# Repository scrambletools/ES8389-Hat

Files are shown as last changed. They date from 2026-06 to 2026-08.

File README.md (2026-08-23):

# Scramble Hat-trik — ES8389 Audio Codec HAT

A compact 4-layer audio I/O HAT that stacks on a Waveshare **ESP32-P4** carrier and
gives it a studio-style balanced input and a headset/line output, bridged to the host
over **I²S** (audio) and **I²C** (control). Its headline trick: it taps the carrier's
**802.3 PoE** rail to generate switchable **~48 V-class phantom power** for condenser
microphones — no separate supply.

> **Target carrier:** a Waveshare ESP32-P4-ETH board with PoE module. You will need to solder taps on the output of the bridge rectifiers of the PoE module and connect those wires to J5 on the hat.

---

## Capabilities

- **Balanced analog input** — Neutrik **XLR / ¼″ (6.35 mm) combo** jack (J1) into the
  ES8389 ADC, with input coupling and ESD protection.
- **PoE-tapped phantom power** — ~48 V phantom (tracks the 46–57 V PoE rail) through the
  standard 6.81 kΩ feed pair, **manually switched** (SW1) and **opto-isolated**, with a
  **white presence LED**, a resettable polyfuse, and a TVS rail clamp.
- **Headset / line output** — 3.5 mm **TRRS** jack (J2): stereo output from the DAC plus
  an **electret mic-bias** input path.
- **Stereo audio codec** — Everest **ES8389** (QFN-24): I²S/PCM audio + I²C control.
- **Clean analog power** — ultra-low-noise LDO (TPS7A2033) and ferrite-isolated AVDD.
- **Isolation barrier** — the phantom / XLR side (PGND) is kept separate from the carrier
  audio ground (AGND), bridged only by a **2.2 nF Y2 safety cap** (C19), with a DNP 0 Ω
  ground-lift option (R14).
- **External display header** — 4-pin **I²C** breakout (J6: 3V3 / GND / SDA / SCL) for an
  off-board display.
- **Manufacturable** — JLCPCB gerbers, drills, BOM and placement files are checked in;
  most parts are machine-assembled.

## Signal & power flow

```
  XLR / 6.35" combo (J1) ──coupling──▶ ES8389 ADC ──▶ I²S ──▶ ESP32-P4 carrier
         ▲ phantom
  PoE (J5) ─F1─▶ SW1 ─opto OK1─▶ P-FET Q1 ─▶ 6.81k feed ─▶ XLR pins 2 & 3

  ESP32-P4 carrier ──▶ I²S ──▶ ES8389 DAC ──coupling──▶ TRRS out (J2)
  ESP32-P4 carrier ◀──▶ I²C ◀──▶ ES8389        (+ external display header J6)
```

## Connectors & controls

| Ref | Part | Function |
|---|---|---|
| **J1** | Neutrik NCJ6FA-H | XLR / ¼″ combo — balanced mic/line **input**; ¼″ side is a Hi-Z **instrument input** with auto-detect *(hand-solder)* |
| **J2** | CUI SJ-3524 TRRS | 3.5 mm headset — stereo **output** + electret mic *(hand-solder)* |
| **J3, J4** | 1×7 sockets (8.5 mm) | mezzanine to the carrier — I²S, I²C, power |
| **J5** | 1×2 header | **PoE** rail input from the carrier's PoE module *(hand-solder)* |
| **J6** | 1×4 header | external **I²C** display (3V3 / GND / SDA / SCL) — *DNP; hand-fit (top side) only for a display harness. Eurorack builds don't need it: the interposer drives the display directly* |
| **SW1** | SPDT slide | **phantom power** on/off (manual) — *DNP; populate only in builds that use phantom.* Unpopulated = phantom permanently off; for switchless always-on phantom, bridge SW1 pads 1–2 instead |

## Key components

| Ref | Part | Role |
|---|---|---|
| **U1** | Everest ES8389 (QFN-24) | stereo audio codec |
| **U2** | TI TPS7A2033 | ultra-low-noise 3.3 V analog LDO |
| **OK1** | Everlight EL3H7 (80 V) | opto-isolated phantom enable |
| **Q1** | Vishay Si2325DS | P-FET phantom high-side switch |
| **F1** | 100 mA / 60 V PPTC | phantom / PoE overcurrent protection |
| **D6** | SMBJ58CA TVS | PoE-rail clamp |
| **D8** | white LED | phantom-present indicator |
| **C19** | 2.2 nF Y2 | isolation-barrier safety cap |

## Board

- **≈ 51.4 × 21.1 mm**, **4-layer** (F.Cu / In1.Cu / In2.Cu / B.Cu), 1.6 mm.
- Components on **both sides** (SMD top + bottom) plus a few through-hole connectors.
- Mechanical CAD (enclosure, mounting brackets, faceplates) is maintained outside this repo.

## Host integration

The codec carries audio over **I²S** and is controlled over **I²C**. Its I²C address is
set by the AD0/AD1 straps (R3/R4); R1/R2 are the SDA/SCL pull-ups. Typical firmware is
**ESPHome** or **ESP-ADF** configured for an external I²S codec.

## Mezzanine pinout (J3 / J4)

The header assignment is chosen so **one unmodified board works on two
hosts**: the Waveshare ESP32-P4-ETH carrier it was designed for, and a
**Raspberry Pi Pico** — the hat's footprint (2.54 mm pitch, ~17.8 mm row
spacing, 51 × 21 mm outline) lands exactly on the Pico's USB-end pins
1–7 / 40–34.

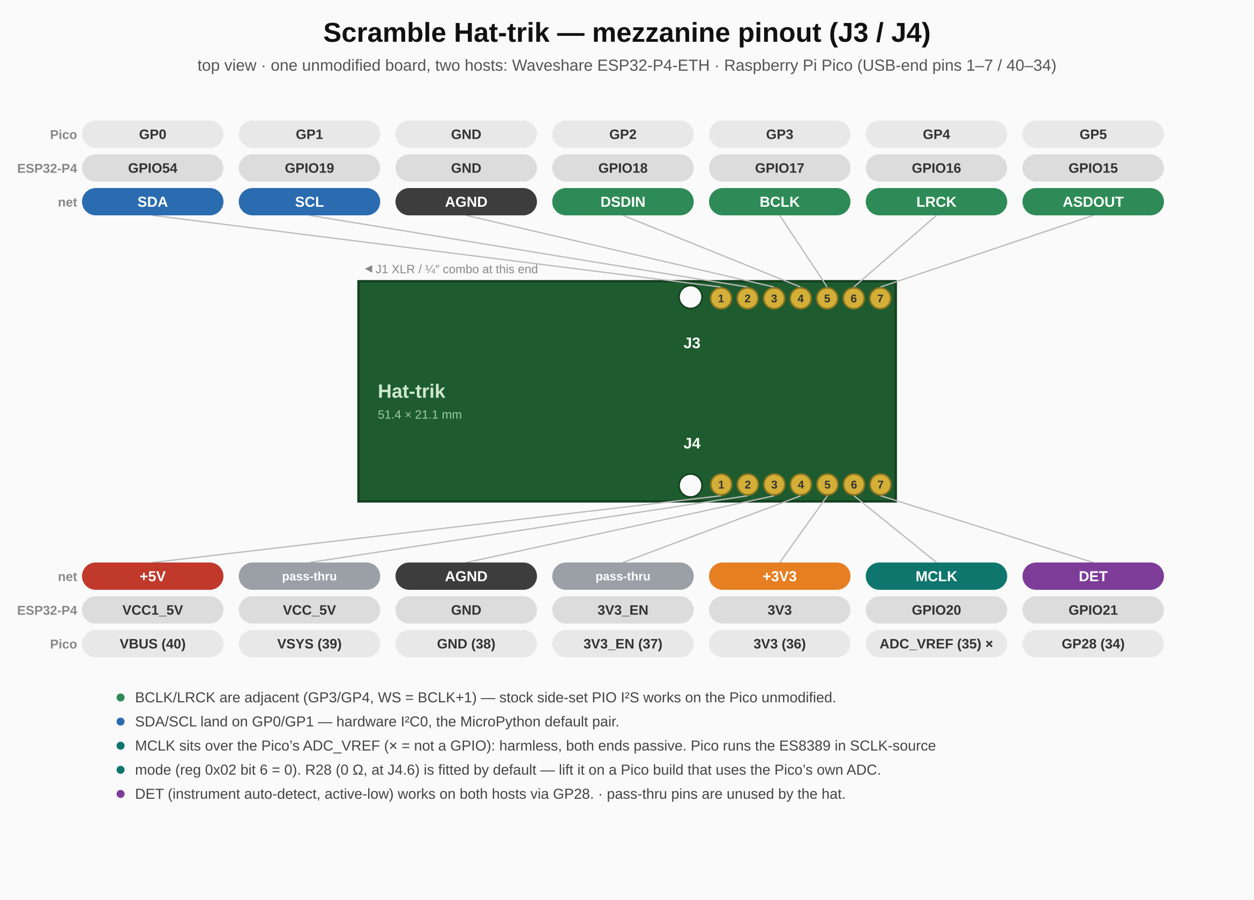
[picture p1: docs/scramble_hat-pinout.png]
Mezzanine pinout


| J3 pad | net | P4-ETH | Pico | | J4 pad | net | P4-ETH | Pico |
|---|---|---|---|---|---|---|---|---|
| 1 | `SDA` | GPIO54 | GP0 | | 1 | `+5V` | VCC1_5V | VBUS |
| 2 | `SCL` | GPIO19 | GP1 | | 2 | *pass* | VCC_5V | VSYS |
| 3 | `AGND` | GND | GND | | 3 | `AGND` | GND | GND |
| 4 | `DSDIN` | GPIO18 | GP2 | | 4 | *pass* | 3V3_EN | 3V3_EN |
| 5 | `BCLK` | GPIO17 | GP3 | | 5 | `+3V3` | 3V3 | 3V3(OUT) |
| 6 | `LRCK` | GPIO16 | GP4 | | 6 | `MCLK` | GPIO20 | ADC_VREF — unused |
| 7 | `ASDOUT` | GPIO15 | GP5 | | 7 | `DET` | GPIO21 | GP28 |

Why it lands this way:

- **BCLK/LRCK adjacent** (GP3/GP4, WS = BCLK + 1) — stock side-set PIO
  I²S implementations work unmodified on the Pico.
- **SDA/SCL on GP0/GP1** — a hardware I²C0 pair and MicroPython's default.
- **MCLK sits over the Pico's ADC_VREF**, which is harmless: both ends are
  passive (ADC_VREF is a filtered rail, the codec's MCLK is a hi-Z input),
  so a full 40-pin header can be fitted. The Pico runs the ES8389 in
  **SCLK-source mode** (reg 0x02 bit 6 = 0 — the codec clocks itself from
  BCLK; supported combos cover 44.1 k/48 k at 16/32-bit). The P4 keeps a
  true MCLK on GPIO20. Never jumper a Pico GPIO into a fitted J4.6.
  **R28** (0 Ω 0805, fitted by default) sits in series right at J4.6:
  lift it on a Pico build that uses the Pico's own ADC, so the hat's MCLK
  trace can't couple noise into ADC_VREF — or use its codec-side pad as
  the MCLK injection point for an advanced Pico build (192 kHz needs a
  real MCLK).
- **DET on GP28** — instrument auto-detect readback works on both hosts.

Pico caveats: `+5V` is VBUS, so the analog LDO only runs on USB power;
**phantom power is unavailable** (no PoE front end — see the phantom
section below); full-duplex I²S needs a custom PIO RX machine against
the TX clocks; no ES8389 driver exists for the Pico yet (port from
ESP-ADF or the mainline Linux `es8389.c`). For low BCLK jitter set
`sys_clk` to 153.6 MHz so 3.072 MHz divides exactly.

## Power & host-connection notes

- **USB-C and PoE at the same time is safe.** The carrier has an onboard
  power mux (PoE-priority P-FET + Schottky), so the supplies never fight
  and the PC's USB port can't be back-driven; the 48 V PoE line side stays
  behind the PoE module's transformer isolation (Y-cap bridge only), with
  or without phantom switched on. Flashing/serial over USB while running
  on PoE is the intended debug workflow.
- **Don't hot-plug USB mid-recording** — the ground-equalization transient
  can print as a pop at +36 dB mic gain. Connect first, then record.
- **Bench use on USB only:** leave phantom off (SW1 open/unpopulated) —
  with phantom on, K1/K2 close and reconnect the unpowered PoE module,
  which injects mains hum into the input.
- **Eurorack builds:** USB-C for flashing/serial works while Synthia
  powers the carrier from the rack — the interposer feeds the carrier's
  pre-mux node (bench-verified), so the same USB power mux applies. Avoid
  leaving USB plugged in with the rack powered off (it back-feeds the
  module's buck output); details in the Synthia repo.

## Phantom power source (the PoE tap)

Phantom power is the one hat feature that needs more than the mezzanine:
the 48 V-class rail is **tapped from the PoE bus** and enters the hat on
**J5** (pin 1 = `TAP_HV` +, pin 2 = `TAP_GND` −). On the ESP32-P4-ETH
carrier, the RJ45 mag-jack's pair centre taps run raw to the H7 header;
the **plug-in PoE module** on H7 carries the bridge rectifiers (BD1/BD2)
that turn them into 37–57 V DC before its isolated DC-DC makes the 5 V.
**Tap the two bridge-rectifier outputs on the PoE module** — `+` to
J5.1, `−` to J5.2. The module has **no connector for the tap**, so the
two leads are hand-soldered directly to the rectifier output pins; keep
them reasonably short:

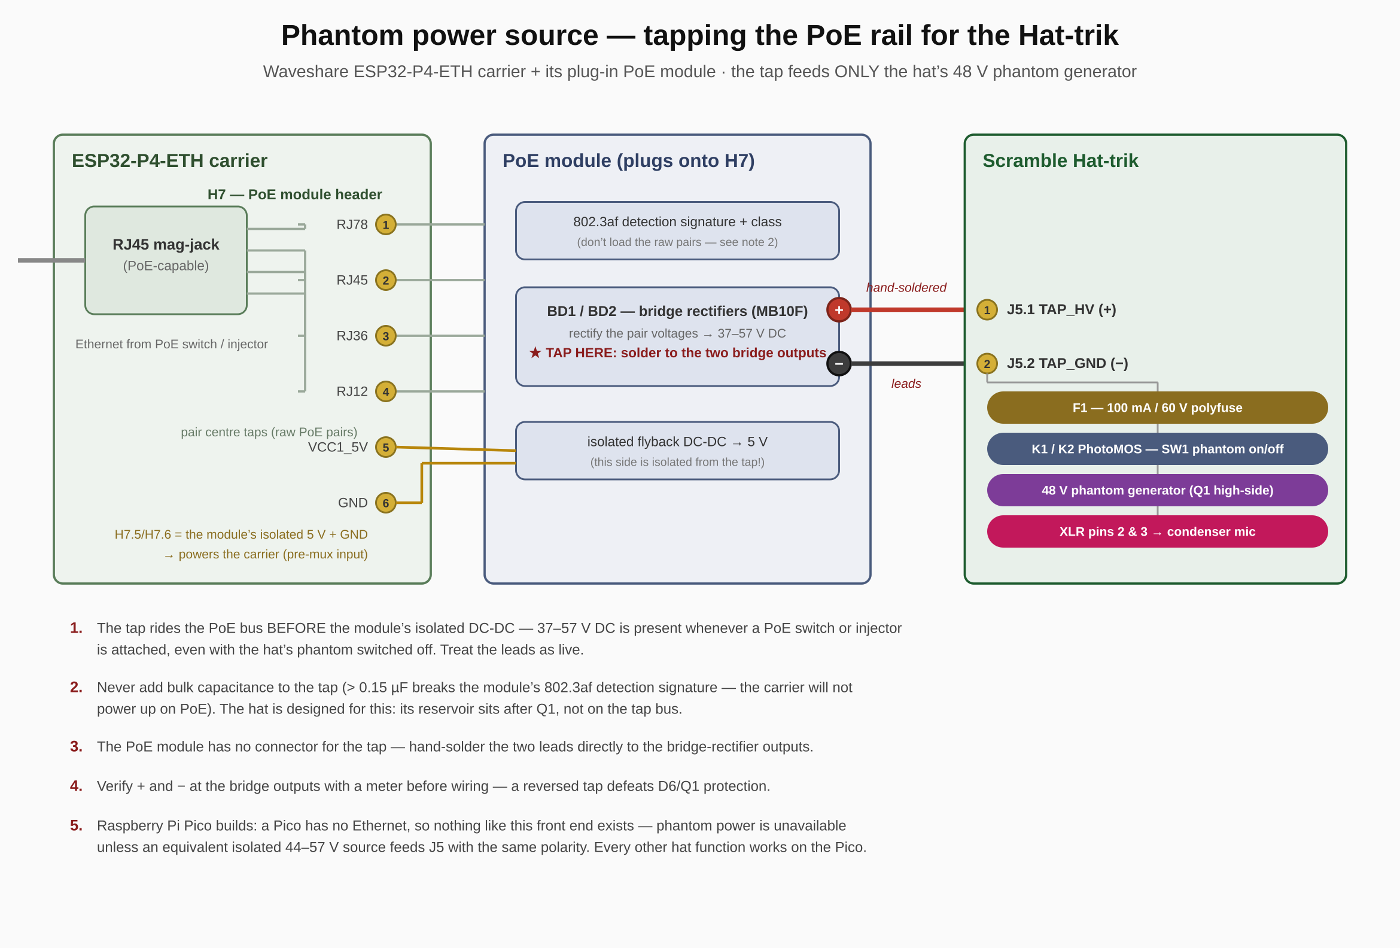
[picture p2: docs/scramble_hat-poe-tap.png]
PoE tap for phantom power


- The tap sits **before** the module's isolation barrier: 37–57 V is
  present whenever a PoE switch/injector is attached, even with SW1 off.
- **Never add bulk capacitance to the tap** (> 0.15 µF breaks the
  module's 802.3af detection signature and the carrier won't power up).
  The hat is designed for this — its reservoir sits after Q1.
- Verify `+`/`−` with a meter at the bridge outputs before wiring; a
  reversed tap defeats the D6/Q1 protection.
- **Raspberry Pi Pico builds: phantom power is unavailable.** A Pico has
  no Ethernet, so nothing like this PoE front end exists — the XLR
  condenser path is dead unless you feed J5 from an equivalent
  **isolated** 44–57 V source with the same polarity. Every other hat
  function (instrument input, dynamic mics, headphone/line out, display)
  works normally on a Pico.

## Microphone setups

Two validated configurations, using the AVB endpoint firmware's controls
(ES8389 PGA via the entity's Mic Gain control; digital gain via the talker's
`ESP_AVB_TALKER_MIC_DIGITAL_GAIN_DB` Kconfig, which also engages an always-on
DC-block ahead of the gain):

| | Condenser (phantom) | Dynamic |
|---|---|---|
| Phantom switch (SW1) | ON | OFF |
| PoE feed (J5) | connected + powered | **disconnect the PoE module** (see note) |
| ES8389 PGA gain | +36 dB | +36 dB (ceiling is +36.5 dB) |
| Digital gain (Kconfig) | 0 dB | **+20 dB** |

Notes:

- **Unpowered PoE module injects mains hum.** With the PoE module installed but
  not powered, the input picks up ~60 Hz mains at near full scale even with SW1
  off — remove/disconnect the module (J5 feed) when running without PoE.
  *(Addressed in the current design: SW1 off now opens both PoE-tap lines
  through the K1/K2 PhotoMOS relays, so the module can stay connected.)*
- Dynamic microphones sit ~20–30 dB below condenser output; the ES8389 PGA
  ceiling (+36.5 dB) alone leaves them ~-40 dBFS, hence the digital gain stage.
- Mic Gain writes above the PGA ceiling **clamp silently** — verify the value
  the response reports, not the value requested.
- The input is wired differential (MIC1P/1N) at the codec; both mic types run
  balanced through the XLR.

## Instrument (guitar) input

The ¼″ side of J1 feeds a high-impedance buffer (U3, ~500 kΩ input) into the
codec's MIC1 channel through an analog mux (U4). Inserting a **mono TS plug**
(guitar cable) shorts the jack's Ring contact to the Sleeve, pulling the
`DET` line low — this automatically switches MIC1 from the XLR mic path to
the buffered instrument path, and is readable by the carrier on **J4.7**
(input, active-low = instrument present). Remove the plug (or use an XLR
mic) and the input returns to the mic path. Phantom power never reaches the
¼″ contacts.

**Hardwiring a guitar without installing the Neutrik connector** — three
connections on the J1 footprint, not two:

| Guitar wire | Pad | Note |
|---|---|---|
| Tip (signal) | either **T** pad | the two T holes are the same net (`GTIP`); one is enough |
| Sleeve (ground) | **S** pad | `PGND`; the larger **G** pad is the same net if a thicker wire is used |
| — | jumper **R → S** | **required.** With no jack fitted, nothing shorts Ring to Sleeve, so `DET` stays high and the mux stays on the (absent) XLR path — the guitar would be silent. The jumper forces instrument mode. Easiest form: populate **R27** (0805 0 Ω, DNP by default) — it shorts `DET` to `PGND` on-board. Remove/leave it off if the Neutrik is fitted. |

**Eurorack module link (J7):** instead of hand-wiring, an optional 1×4
female socket **J7** (8.5 mm stacking, same series as J3/J4, DNP by
default) direct-mates the **Synthia** eurorack interposer's J8 header. Populate J7
**only when J1 is absent** (they use the same input path), and populate
**R27** with it (the module's input jack can't pull `DET` low). Pinout:
1 = `GTIP`, 2 = `PGND`, 3 = `AGND`, 4 = `HP_L_OUT` — signals on the outer
pins with both grounds between them.

**Eurorack + display:** the interposer drives a display directly from its
own display socket (J10, on the main GND/3V3/I²C nets), so **J6 can stay
DNP in eurorack builds** — no bottom-side fitting needed. Fit J6 (top
side) only for a normal display harness in non-rack builds.

**Cable:** use two-core shielded cable (the input is high impedance and
hums otherwise) — one core to **T** (signal), the other core to **S**
(return), and the **shield joined to S at the hat end only**; at the guitar
end connect just the two cores (tip / sleeve) and trim + insulate the
shield. The return current then flows in the tightly-coupled core pair
while the shield does pure screening — bonding it at both ends would let
ground-loop and pickup currents flow through it in series with the signal.
For very short runs (a few cm) plain coax — center to T, shield as the
return to S, connected at both ends — also works.

## Mono amplifier output (hardwiring J2)

To feed a mono amplifier that expects only tip and sleeve, skip the 3.5 mm jack
and solder wires directly to the J2 footprint. **Careful:** J2 is wired as a
**CTIA TRRS** headset jack, so the pad named `S` is *not* ground — on CTIA the
physical sleeve is the microphone conductor.

| Amp wire | Pad | Note |
|---|---|---|
| Tip (signal) | **T** | `HP_L_OUT` — left audio channel |
| Sleeve (ground) | **TN** | `AGND` — audio ground. **Do not use the `S` pad**: it is the headset-mic line (`MIC2_RAW`) and carries mic bias — grounding it gives hum and injects into the MIC2 input. |

Notes:

- This taps the **left channel only**; have firmware output a mono downmix if
  the source is stereo. Do **not** bridge the `T` and `R` pads to "sum" the
  channels — that shorts the two DAC output stages into each other. (A passive
  sum, if ever wanted, is a ~1 kΩ resistor from each of T and R into the amp
  tip.)
- An amp input (typically ≥10 kΩ) is a much lighter load than headphones, so
  the 22 µF output coupling caps give essentially full bass extension here.
- Unlike the J1 guitar hardwire, **no jumper is required** — J2 has no
  plug-detect circuit.
- **Cable:** use two-core shielded cable — one core to **T** (signal), the
  other core to **TN** (return), **shield joined to TN at the hat end
  only**; at the amp end connect just the two cores (tip / sleeve) and
  trim + insulate the shield. This keeps the shield free of audio and
  ground-loop current (which its resistance would otherwise convert to hum
  in series with the signal) while still screening the run. This link is
  forgiving (low-Z source into a ≥10 kΩ amp input), so for runs under
  ~10 cm plain coax with the shield as the return, connected at both ends,
  is also fine.

## Repository layout

| Path | Contents |
|---|---|
| `scramble_hat.kicad_sch` / `.kicad_pcb` | hierarchical schematic + layout |
| `BOM.csv` | bill of materials — **single source of truth** |
| `fab/` | JLCPCB gerbers, drills, BOM, CPL — see [`fab/README.md`](fab/README.md) |
| `tools/gen_fab.py` | regenerate every production file from the design |
| `tools/check_sync.py` | verify schematic ↔ PCB netlist agreement |
| `lib/` | project symbols, footprints, 3D models |
| `docs/` | schematic + silkscreen PDFs |

## Manufacturing

See **[`fab/README.md`](fab/README.md)** for the full ordering guide. In short: JLCPCB
fabricates and assembles most parts; you **hand-solder J1, J2, J5 and C19** (the Y-cap),
and **R14 is left unpopulated** (DNP ground-lift jumper). **J6** (display header) is also
DNP — hand-fit it only when a display is used (top side normally, bottom side for the
eurorack stack). Regenerate all fab outputs with:

```sh
python3 tools/gen_fab.py
```

> ⚠️ Before committing an assembly order, verify part rotations in JLCPCB's preview —
> especially **U1** (the QFN's rotation is applied manually and is a best estimate).

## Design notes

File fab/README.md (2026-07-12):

# Scramble Hat-trik — Fabrication & Assembly Files

Production files for **JLCPCB** (PCB fab + PCBA assembly). Board is an ES8389
audio codec HAT for the Waveshare ESP32-P4-Nano carrier (XLR/¼" combo input,
PoE-tapped phantom power, TRRS output, I²S/I²C to the carrier).

- **Board size:** ~51.4 × 21.1 mm
- **Layers:** 4 (F.Cu / In1.Cu / In2.Cu / B.Cu)
- **Assembly:** 28 BOM line items (48 placements/board) machine-assembled;
  3 connectors + 1 Y-cap hand-soldered; 1 part unpopulated.

> Regenerate everything with **`python3 tools/gen_fab.py`** (see the bottom).
> These files are committed from the design in the repo root; don't hand-edit them.

---

## Files

| File | Purpose |
|---|---|
| `scramble_hat-gerbers.zip` | **PCB fab** — all gerbers + drills (upload this) |
| `scramble_hat-*.gbr`, `*.drl`, `*.gbrjob` | Loose copies of the layers/drills in the zip |
| `scramble_hat-BOM.csv` / `.xlsx` | **Assembly BOM** — JLCPCB upload format (Comment, Designator, Footprint, LCSC#) |
| `Sample-BOM_JLCSMT.xlsx`, `JLCSMT_Sample_CPL1.xlsx` | JLCPCB's blank format templates (reference only) |
| `scramble_hat-CPL.csv` | **Placement file** — generated by `tools/gen_fab.py` with JLCPCB rotation corrections + the U1 fix baked in (still verify — see below) |

---

## How to order

### 1. PCB fabrication
Upload **`scramble_hat-gerbers.zip`**. Set **4 layers**; the rest can be
JLCPCB defaults (1.6 mm, HASL/ENIG, no controlled impedance required).

### 2. PCB assembly (PCBA)
1. **Enable "PCBA"** and turn on **through-hole / THT component assembly** at
   checkout — several parts are through-hole (see the assembled-THT list below).
2. Upload the **BOM**: `scramble_hat-BOM.csv`.
3. Upload the **CPL / placement file** — **you must generate this** (see next section).

### 3. ⚠️ CPL / placement — verify rotations before ordering
`scramble_hat-CPL.csv` is generated by `tools/gen_fab.py`. Its rotations were
**cross-validated against the KiCad Fabrication Toolkit plugin** — they match on
every placed part — and it additionally corrects **U1** (`+270°`), which the
plugin's auto-database misses because of the custom `ES8389_QFN24_P0.35mm` name.

Even so, **verify every rotation in JLCPCB's assembly preview** before ordering —
especially **U1 (QFN)**, whose correction is a best estimate. The preview overlays
each part on its land; rotate anything that looks off.

Parts carrying a rotation correction (double-check these first): `U1`, `U2`, `Q1`,
`D1`, `D2`, `OK1`. The CPL already excludes the hand-solder (J1/J2/J5) and DNP
(R14) parts via their `exclude_from_pos_files` / `dnp` PCB flags.

---

## Who solders what

| Set | Parts | Notes |
|---|---|---|
| **JLCPCB — SMT** | everything not listed below | machine-placed |
| **JLCPCB — THT** (enable at checkout) | `J3`, `J4` (carrier sockets), `SW1` (slide switch), `J6` (I²C header) | wave/hand-soldered by JLCPCB |
| **You — hand-solder after arrival** | `J1` (XLR/¼" combo jack), `J2` (TRRS jack), `J5` (PoE header), `C19` (Y2 safety cap) | J2 is out of stock at LCSC (source separately); J5 is where you wire the PoE module; C19 is a user-sourced 7.5 mm Y2 disc (Murata DE2E3 / TDK CS11) — kept off the JLC line so its niche stock never blocks the order |
| **Unpopulated (DNP)** | `R14` | 0 Ω ground-lift jumper, deliberately left off |

---

## Sourcing notes
- **F1** polyfuse (`1812L010/60DR`, C207062) — stock is thin (~120); re-check at order time. It's the voltage-critical 60 V part — do not substitute a lower-voltage 1812.
- Extended-library parts (U1, EL3H7 opto, TVS, R16, the 6.81 k, J6, etc.) each carry JLCPCB's one-time extended-part fee.
- Per-board BOM parts ≈ **$8** at qty-10 pricing (dominated by the J1/J2 jacks); budget more for the one-time extended fees.

---

## Regenerating these files
From the repo root, with KiCad closed:

```sh
python3 tools/gen_fab.py
```

One script rebuilds the gerbers, drills, zip, **BOM** (from the root `BOM.csv` —
single source of truth — with DNP rows dropped) and the **CPL** (with JLCPCB
rotation corrections). Needs `kicad-cli` on PATH and `openpyxl` for the `.xlsx`
BOM. The rotation-correction table is at the top of the script — extend it when
you add parts, and always re-verify in JLCPCB's preview.

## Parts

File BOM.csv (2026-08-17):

Comment | Designator | Qty | MPN | Manufacturer | Footprint | LCSC Part # | JLCPCB Class | Mount | DNP | Unit Price USD | Notes | Datasheet
ES8389 audio codec | U1 | 1 | ES8389 | Everest Semi | QFN-24 3x3 P0.35mm | C22380673 | Extended | SMT |  | 0.712 | Custom 0.35mm-pitch footprint (scramble_hat lib) | https://datasheet.lcsc.com/datasheet/pdf/4ae5a2e8327541a33b0c2afa9b0074da.pdf?productCode=C22380673
Ultra-low-noise LDO 3.3V | U2 | 1 | TPS7A2033PDBVR | Texas Instruments | SOT-23-5 | C2862740 | Extended | SMT |  | 0.2102 | AVDD analog LDO; +5V -> +3V3_A | https://datasheet.lcsc.com/datasheet/pdf/e9493c53ea71c523359aed2b3e8071a4.pdf?productCode=C2862740
Optocoupler 80V | OK1 | 1 | EL3H7(C)(TA)-VG | Everlight | SOP-4-1.27mm | C17549577 | Extended | SMT |  | 0.0741 | PHANTOM_EN isolation; 80V Vceo; SOP-4 1.27mm half-pitch; pinout 1=A 2=K 3=E 4=C. Same die/package/CTR-bin as EL3H7(C)(TA)-G (C92243, went stock-0 2026-07-26); -VG = halogen-free packing. CTR 200-400%. | https://www.everlighteurope.com/custom/files/datasheets/DPC-0000031.pdf
P-MOSFET 150V | Q1 | 1 | Si2325DS-T1-GE3 | Vishay | SOT-23 | C60773 | Extended | SMT |  | 0.4946 | Phantom switch; gate clamped by D7 | https://datasheet.lcsc.com/datasheet/pdf/8db77570eae4643cba5e4135ab2c0e7e.pdf?productCode=C60773
ESD diode, 3.3V bidir | D1, D2 | 2 | PESD3V3L1BA-N | BORN | SOD-323 | C316020 | Extended | SMT |  | 0.0611 | Mic-line ESD (was 4-line PESD3V3L4UG/C70500 using 1 of 4 channels). Bidirectional 2-pin: no polarity/rotation. Saves ~$0.14/board | https://datasheet.lcsc.com/datasheet/pdf/a036bfae0471726dc4b012d9a313715c.pdf?productCode=C316020
TVS 58V 600W bidir | D6 | 1 | SMBJ58CA | Littelfuse | SMA | C151267 | Extended | SMT |  | 0.121 | PoE rail clamp | https://datasheet.lcsc.com/datasheet/pdf/4ab84a227fae39f9eac85241b8264ead.pdf?productCode=C151267
Zener 12V 0.5W | D7 | 1 | MMSZ5242BT1G | onsemi | SOD-123 | C82050 | Basic/Ext | SMT |  | 0.0354 | Q1 gate clamp | https://datasheet.lcsc.com/datasheet/pdf/03657490163bd8bf58522f8bf8ee19e0.pdf?productCode=C82050
LED, white | D8 | 1 | KT-0805W | Hubei KENTO | 0805 | C34499 | Basic | SMT |  | 0.0203 | Phantom-present indicator (white); KT-0805W Basic in-stock | https://datasheet.lcsc.com/datasheet/pdf/48953f05e6e6e0a517af2e319c9c297c.pdf?productCode=C34499
PPTC 100mA hold / 60V | F1 | 1 | 1812L010/60DR | Littelfuse | 1812 | C207062 | Extended | SMT |  | 0.2151 | True 1812 (matches board land); 100mA hold/300mA trip. prior 0ZCJ0005FF2E/C194141 is 1206 - wrong size | https://datasheet.lcsc.com/datasheet/pdf/f489f06aaead3504c46a5f46e8004a19.pdf?productCode=C207062
Ferrite 600R @100MHz | FB1 | 1 | BLM18AG601SN1D | Murata | 0603 | C19330 | Basic/Ext | SMT |  | 0.0149 | AVDD ferrite | https://datasheet.lcsc.com/datasheet/pdf/2d503a4b167da9bb5d0eb4a3fa711314.pdf?productCode=C19330
100nF 50V X7R | C1, C3, C4, C27, C28, C29 | 6 | CC0402KRX7R9BB104 | Yageo | 0402 | C131394 | Basic | SMT |  | 0.0157 |  | https://datasheet.lcsc.com/datasheet/pdf/23ccee80ee542e7cf156a772bb589942.pdf?productCode=C131394
1uF 25V X5R | C2, C5, C7, C8, C9, C12, C13, C20, C21, C23, C24, C25, C26 | 13 | CL05A105KA5NQNC | Samsung | 0402 | C52923 | Basic | SMT |  | 0.0266 |  | https://datasheet.lcsc.com/datasheet/pdf/02336ea48ea44ca18c72517dd3cb7b47.pdf?productCode=C52923
10uF 16V X5R | C6 | 1 | GRM21BR61C106KE15L | Murata | 0805 | C77075 | Basic | SMT |  | 0.0716 | AVDD bulk | https://datasheet.lcsc.com/datasheet/pdf/a4d1e2744bd5d44ba57842651a3fd598.pdf?productCode=C77075
1uF 100V X7R | C10, C11 | 2 | CC0805KKX7R0BB105 | Yageo | 0805 | C5370002 | Extended | SMT |  | 0.1307 | XLR coupling (phantom side); 100V for margin | https://datasheet.lcsc.com/datasheet/pdf/23ccee80ee542e7cf156a772bb589942.pdf?productCode=C5370002
22uF 10V X5R | C14, C15 | 2 | CL21A226MPQNNNE | Samsung | 0805 | C29277 | Extended | SMT |  | 0.1722 | HP coupling | https://datasheet.lcsc.com/datasheet/pdf/02336ea48ea44ca18c72517dd3cb7b47.pdf?productCode=C29277
100nF 100V X7R | C17, C30 | 2 | 0805B104K101NT | Fenghua | 0805 | C89258 | Extended | SMT |  | 0.026 | C17 = tap-line bridge; C30 = V_PHANTOM bypass at Q1 drain (PoE-converter hash filter; keep OFF the tapped bus - 802.3 detection limit). 100V rating required (57V rail). | https://datasheet.lcsc.com/datasheet/pdf/9f6ef17093b8d551f8b17af0626ff758.pdf?productCode=C89258
1uF 100V X7R | C18 | 1 | CL31B105KCHNNNE | Samsung | 1206 | C13832 | Extended | SMT |  | 0.1396 | Q1 gate soft-start | https://datasheet.lcsc.com/datasheet/pdf/02336ea48ea44ca18c72517dd3cb7b47.pdf?productCode=C13832
2.2nF Y2 300VAC | C19 | 1 | DE2E3SA222MA3BT02F | Murata | Disc TH 7.5mm | C524537 | n/a | TH | DNP | 0.087 | Hand-solder by user (Y2 safety cap; NOT JLC-assembled). X1/Y2 300/250VAC 2.2nF 7.5mm disc; source DigiKey/Mouser (Murata DE2E3) or TDK CS11-E2GA222MYNSA equivalent LCSC ALT (in stock 42k, $0.03): Hongzhi Y26F1E222M / C332371, Y2 250VAC 2.2nF P7.5 - same land. | https://datasheet.lcsc.com/datasheet/pdf/d99197b87f9afabff400cdbfcd3b51ea.pdf?productCode=C524537
2.2uF 10V X5R | C22 | 1 | CL05A225KP5NSNC | Samsung | 0402 | C107369 | Basic | SMT |  | 0.0239 | LDO output cap | https://datasheet.lcsc.com/datasheet/pdf/02336ea48ea44ca18c72517dd3cb7b47.pdf?productCode=C107369
10k 1% | R1, R2, R3, R4, R25 | 5 | RC0402FR-0710KL | Yageo | 0402 | C60490 | Extended | SMT |  | 0.0059 | I2C pullups + AD0/AD1 straps. C# was C25744 = UNI-ROYAL 0402WGF1002TCE (Basic) but now OUT OF STOCK; switched to the matching Yageo MPN C60490 (in stock ~92k). Verify Basic/Extended badge in JLC UI | https://datasheet.lcsc.com/datasheet/pdf/b426be3ce22c6de3e0c3a2248e49159e.pdf?productCode=C60490
6.81k 1% | R5, R6 | 2 | ERJ6ENF6811V | Panasonic | 0805 | C3025619 | Extended | SMT |  | 0.0082 | Phantom feed pair (no JLCPCB Basic for 6.81k 0805) | https://datasheet.lcsc.com/datasheet/pdf/ac61a13441f28ab6046e65784bfab8d2.pdf?productCode=C3025619
2.2k 1% | R7, R20 | 2 | AC0402FR-072K2L | Yageo | 0402 | C144773 | Basic | SMT |  | 0.0057 | Mic bias; C# C25879 stock-0 at LCSC 2026-07-26; swapped to C144773. | https://datasheet.lcsc.com/datasheet/pdf/3511efb0564cb1711d9237ab09d6e97b.pdf?productCode=C144773
33R 1% | R9, R10, R24 | 3 | RC0402FR-0733RL | Yageo | 0402 | C138002 | Basic | SMT |  | 0.0056 | HP output series; C# C25105 stock-0 at LCSC 2026-07-26; swapped to C138002. | https://datasheet.lcsc.com/datasheet/pdf/b426be3ce22c6de3e0c3a2248e49159e.pdf?productCode=C138002
100k 1% | R11, R13, R19, R22, R23 | 5 | RC0402FR-07100KL | Yageo | 0402 | C60491 | Basic | SMT |  | 0.0061 | Q1 gate pullup / opto pulldown; C# C25741 stock-0 at LCSC 2026-07-26; swapped to C60491. | https://datasheet.lcsc.com/datasheet/pdf/b426be3ce22c6de3e0c3a2248e49159e.pdf?productCode=C60491
1k 1% | R12 | 1 | RC0402FR-071KL | Yageo | 0402 | C106235 | Basic | SMT |  | 0.0062 | Opto LED current limit (switch -> opto); C# C11702 stock-0 at LCSC 2026-07-26; swapped to C106235. | https://datasheet.lcsc.com/datasheet/pdf/b426be3ce22c6de3e0c3a2248e49159e.pdf?productCode=C106235
0R | R14 | 1 | RC0402JR-070RL | Yageo | 0402 |  | n/a | DNP | DNP | 0.02 | Ground-lift jumper - not populated (true DNP)
15k 1% 1/4W | R16 | 1 | AC0805FR-7W15KL | Yageo | 0805 | C20142753 | Extended | SMT |  | 0.0085 | D8 LED current-limit (bright ~3mA); 1/4W anti-surge ~193mW at 57V rail | https://datasheet.lcsc.com/datasheet/pdf/3511efb0564cb1711d9237ab09d6e97b.pdf?productCode=C20142753
XLR / 6.35mm combo jack | J1 | 1 | NCJ6FA-H | Neutrik | TH combo | C368458 | n/a | TH | DNP | 2.6072 | Hand-solder (TH). Switched combo (A type), ~$1.82 vs FI $4.34; jack switch contacts unused | https://datasheet.lcsc.com/datasheet/pdf/9e398f1fdd271e3584b460a9821f2988.pdf?productCode=C368458
3.5mm TRRS jack | J2 | 1 | SJ-3524-SMT-TR | CUI | SMT |  | n/a | SMT | DNP | 1.40 | SJ-3524 family OUT OF STOCK at LCSC+JLCPCB (2026-06) - hand-solder from DigiKey 281298 (base -TR, 67k stock; any color variant fits) | https://www.sameskydevices.com/product/interconnect/connectors/audio-connectors/jacks/sj-3524-smt-tr
1x7 female socket, 8.5mm | J3, J4 | 2 | PM254V-11-07-H85 | XFCN | PinSocket_1x07_2.54mm TH | C2832270 | THT | TH |  | 0.0976 | JLCPCB THT-assembled (enable THT components at checkout); 8.5mm stack height | https://datasheet.lcsc.com/datasheet/pdf/5aa023c30ffb4f607882b69ea05af7aa.pdf?productCode=C2832270
1x2 pin header | J5 | 1 | PRPC002SAAN-RC | Sullins | PinHeader_1x02_2.54mm TH |  | n/a | TH | DNP | 0.30 | PoE module connection - hand-solder
1x4 pin header | J6 | 1 | B-2100S04P-A110 | Ckmtw | PinHeader_1x04_2.54mm TH | C124378 | Extended | TH | DNP | 0.055 | Hand-fit per build: top side for a display harness, BOTTOM side for the eurorack stack (mates interposer J9). Pinout 1=AGND 2=+3V3 3=SCL 4=SDA | https://datasheet.lcsc.com/datasheet/pdf/219f7e7eb5f34457895b2c164313179f.pdf?productCode=C124378
1x4 female socket, 8.5mm | J7 | 1 | PM254V-11-04-H85 | XFCN | PinSocket_1x04_2.54mm TH | C541851 | Extended | TH | DNP | 0.0703 | OPTIONAL: populate only when J1 is absent; direct-mates eurorack module J8 (same H85 stack series as J3/J4). Pin 1=GTIP 2=PGND 3=AGND 4=HP_L_OUT | https://datasheet.lcsc.com/datasheet/pdf/7912db05a9479e06d287e74aeb027dc2.pdf?productCode=C541851
0R jumper 0805 | R27 | 1 | 0805W8F0000T5E | UNI-ROYAL | 0805 | C17477 | Basic | SMT | DNP | 0.0101 | OPTIONAL: populate to force instrument mode (DET->PGND, replaces J1 ring-short); required when input arrives via J7 | https://datasheet.lcsc.com/datasheet/pdf/0a975aaa49b7c97f38a963127be4a823.pdf?productCode=C17477
0R jumper 0805 | R28 | 1 | 0805W8F0000T5E | UNI-ROYAL | 0805 | C17477 | Basic | SMT |  | 0.0101 | MCLK series link (J4.6 -> codec), fitted by default; lift only on a Pico build that uses the Pico's own ADC (isolates the MCLK trace from ADC_VREF) | https://datasheet.lcsc.com/datasheet/pdf/0a975aaa49b7c97f38a963127be4a823.pdf?productCode=C17477
SPDT slide switch (phantom on/off) | SW1 | 1 | SS-12D00-G3 | SOFNG | SW_Slide_SS-12D00-G3 TH | C22355741 | THT | TH | DNP | 0.0472 | OPTIONAL (DNP by default): populate for manual phantom on/off. Unpopulated = phantom permanently OFF (PHANTOM_SW floats, no LED drive). For always-on phantom without the switch, bridge pads 1-2 (+3V3 to PHANTOM_SW). | https://datasheet.lcsc.com/datasheet/pdf/7357551f1ab94cd5763cc9d7033faef8.pdf?productCode=C22355741
PhotoMOS SSR 400V (tap disconnect) | K1, K2 | 2 | KAQY214S | Cosmo | SOP-4 3.8x4.1mm | C2890344 | Extended | SMT |  | 0.6812 | 1-form-A AC/bidirectional MOSFET-output SSR; K1 breaks V_PoE tap, K2 breaks PGND tap, when phantom off (kills dynamic-mic buzz). Input LED off PHANTOM_SW via R17/R18. VERIFY pinout 1=A/2=K/3,4=load per C2890344; verify JLCPCB SMT-assembly vs hand-solder. | https://datasheet.lcsc.com/datasheet/pdf/c42aed2cb222c7a8c08f3ade74b70e5b.pdf?productCode=C2890344
470R 1% (PhotoMOS LED limit) | R17, R18 | 2 | RC0402FR-07470RL | Yageo | 0402 | C114877 | Basic | SMT |  | 0.0052 | K1/K2 input-LED current limit (~4.5mA at 3V3; KAQY214S Vf 1.2V, IFON<=3mA). Yageo RC0402FR family match; 306k stock; JLCPCB Economic-eligible. | https://datasheet.lcsc.com/datasheet/pdf/b426be3ce22c6de3e0c3a2248e49159e.pdf?productCode=C114877
Op-amp Hi-Z buffer (RRIO CMOS) | U3 | 1 | TLV9061IDBVR | Texas Instruments | SOT-23-5 | C398358 | Extended | SMT |  | 0.0967 | Guitar 1/4in Hi-Z buffer (~1M in), unity follower on +5V; drives mux U4. Pinout 1=OUT 2=V- 3=IN+ 4=IN- 5=V+ | https://datasheet.lcsc.com/datasheet/pdf/b3f500e21835dc38634fe987feaa838a.pdf?productCode=C398358
Analog switch triple SPDT | U4 | 1 | 74HC4053PW | Nexperia | TSSOP-16 | C5648 | Extended | SMT |  | 0.2602 | Mic/instrument mux: MIC1P/MIC1N source = XLR mic (no plug) or buffered guitar + PGND ref (plug). Select=DET (jack ring; also routed to J3.7 for firmware readback). +3V3 supply so DET/select are 3.3V-native and GPIO-safe; analog range 0-3.3V covers codec-bias signals. 2 of 3 sections used (Z spare). VERIFY TSSOP-16 rotation in JLCPCB preview | https://datasheet.lcsc.com/datasheet/pdf/176a996d087210c9e4d002f82a5fe329.pdf?productCode=C5648
1M 1% | R21, R26 | 2 | RC0402FR-071ML | Yageo | 0402 | C138033 | Basic | SMT |  | 0.0055 | Guitar buffer input bias -> ~1M input impedance; C# C26083 stock-0 at LCSC 2026-07-26; swapped to C138033. | https://datasheet.lcsc.com/datasheet/pdf/b426be3ce22c6de3e0c3a2248e49159e.pdf?productCode=C138033
ESD diode bidir 5.5V | D9 | 1 | TPD1E10B06DPYR | Texas Instruments | X1-SON-2 0.6x1.0mm | C48260 | Extended | SMT |  | 0.0414 | Guitar tip ESD clamp (GTIP-PGND); bidirectional +/-5.5V, 12pF. Tiny DFN - JLC-assembled; hand-rework alt: PESD5V0S1BB/C97640 SOD-523 | https://datasheet.lcsc.com/datasheet/pdf/338eb197fbc247888eaf2230887550ac.pdf?productCode=C48260

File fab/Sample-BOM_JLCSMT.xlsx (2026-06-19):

Comment | Designator | Footprint | JLCPCB Part #（optional）
100uF | C1 | CAP-SMD_L3.5-W2.8 | C16133
15K | R5,R6 | R0603 | C22809
DC-005-20A_C136744 | DC1 | DC-IN-TH_DC-005-20A | C136744
Header-Female-2.54_1x8 | P2,P3 | HDR-TH_8P-P2.54-V | C27438
K2-1102DP-C4SW-04 | SW1 | KEY-TH_4P-L6.0-W6.0-P4.50-LS6.5 | C110153
ATMEGA328P-PU | U1 | DIP-28_L34.6-W7.3-P2.54-LS10.2-BL | C33901
670688000 | USB1 | USB-B-TH_67068-8000 | C114097

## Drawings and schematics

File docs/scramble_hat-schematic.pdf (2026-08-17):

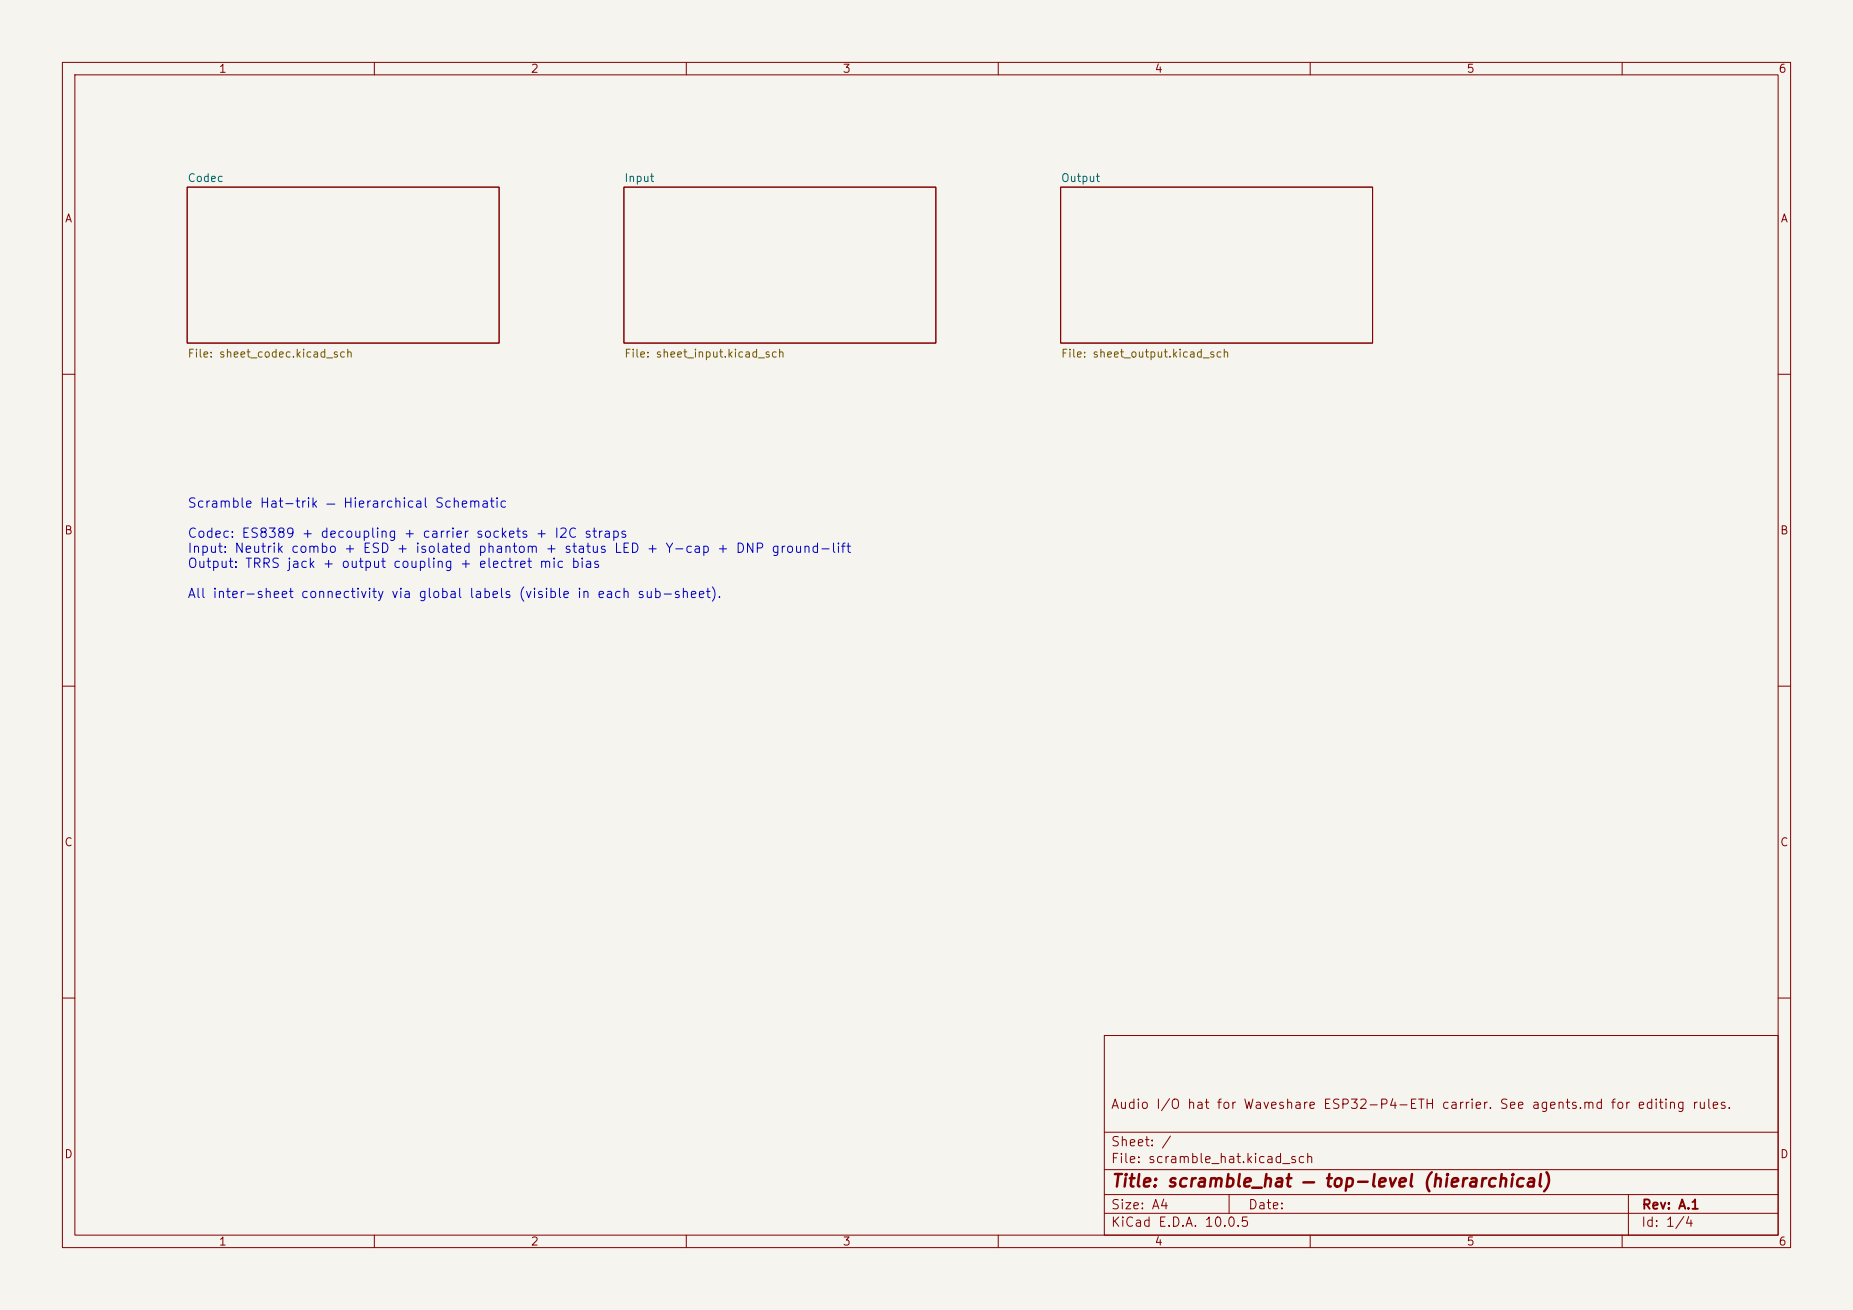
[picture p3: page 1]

Scramble Hat-trik — Hierarchical Schematic

Codec: ES8389 + decoupling + carrier sockets + I2C straps
Input: Neutrik combo + ESD + isolated phantom + status LED + Y-cap + DNP ground-lift
Output: TRRS jack + output coupling + electret mic bias

All inter-sheet connectivity via global labels (visible in each sub-sheet).

Audio I/O hat for Waveshare ESP32-P4-ETH carrier. See agents.md for editing rules.

Sheet: /
File: scramble_hat.kicad_sch
Title: scramble_hat — top-level (hierarchical)

Size: A4 | Rev: A.1
KiCad E.D.A. 10.0.5 | Id: 1/4

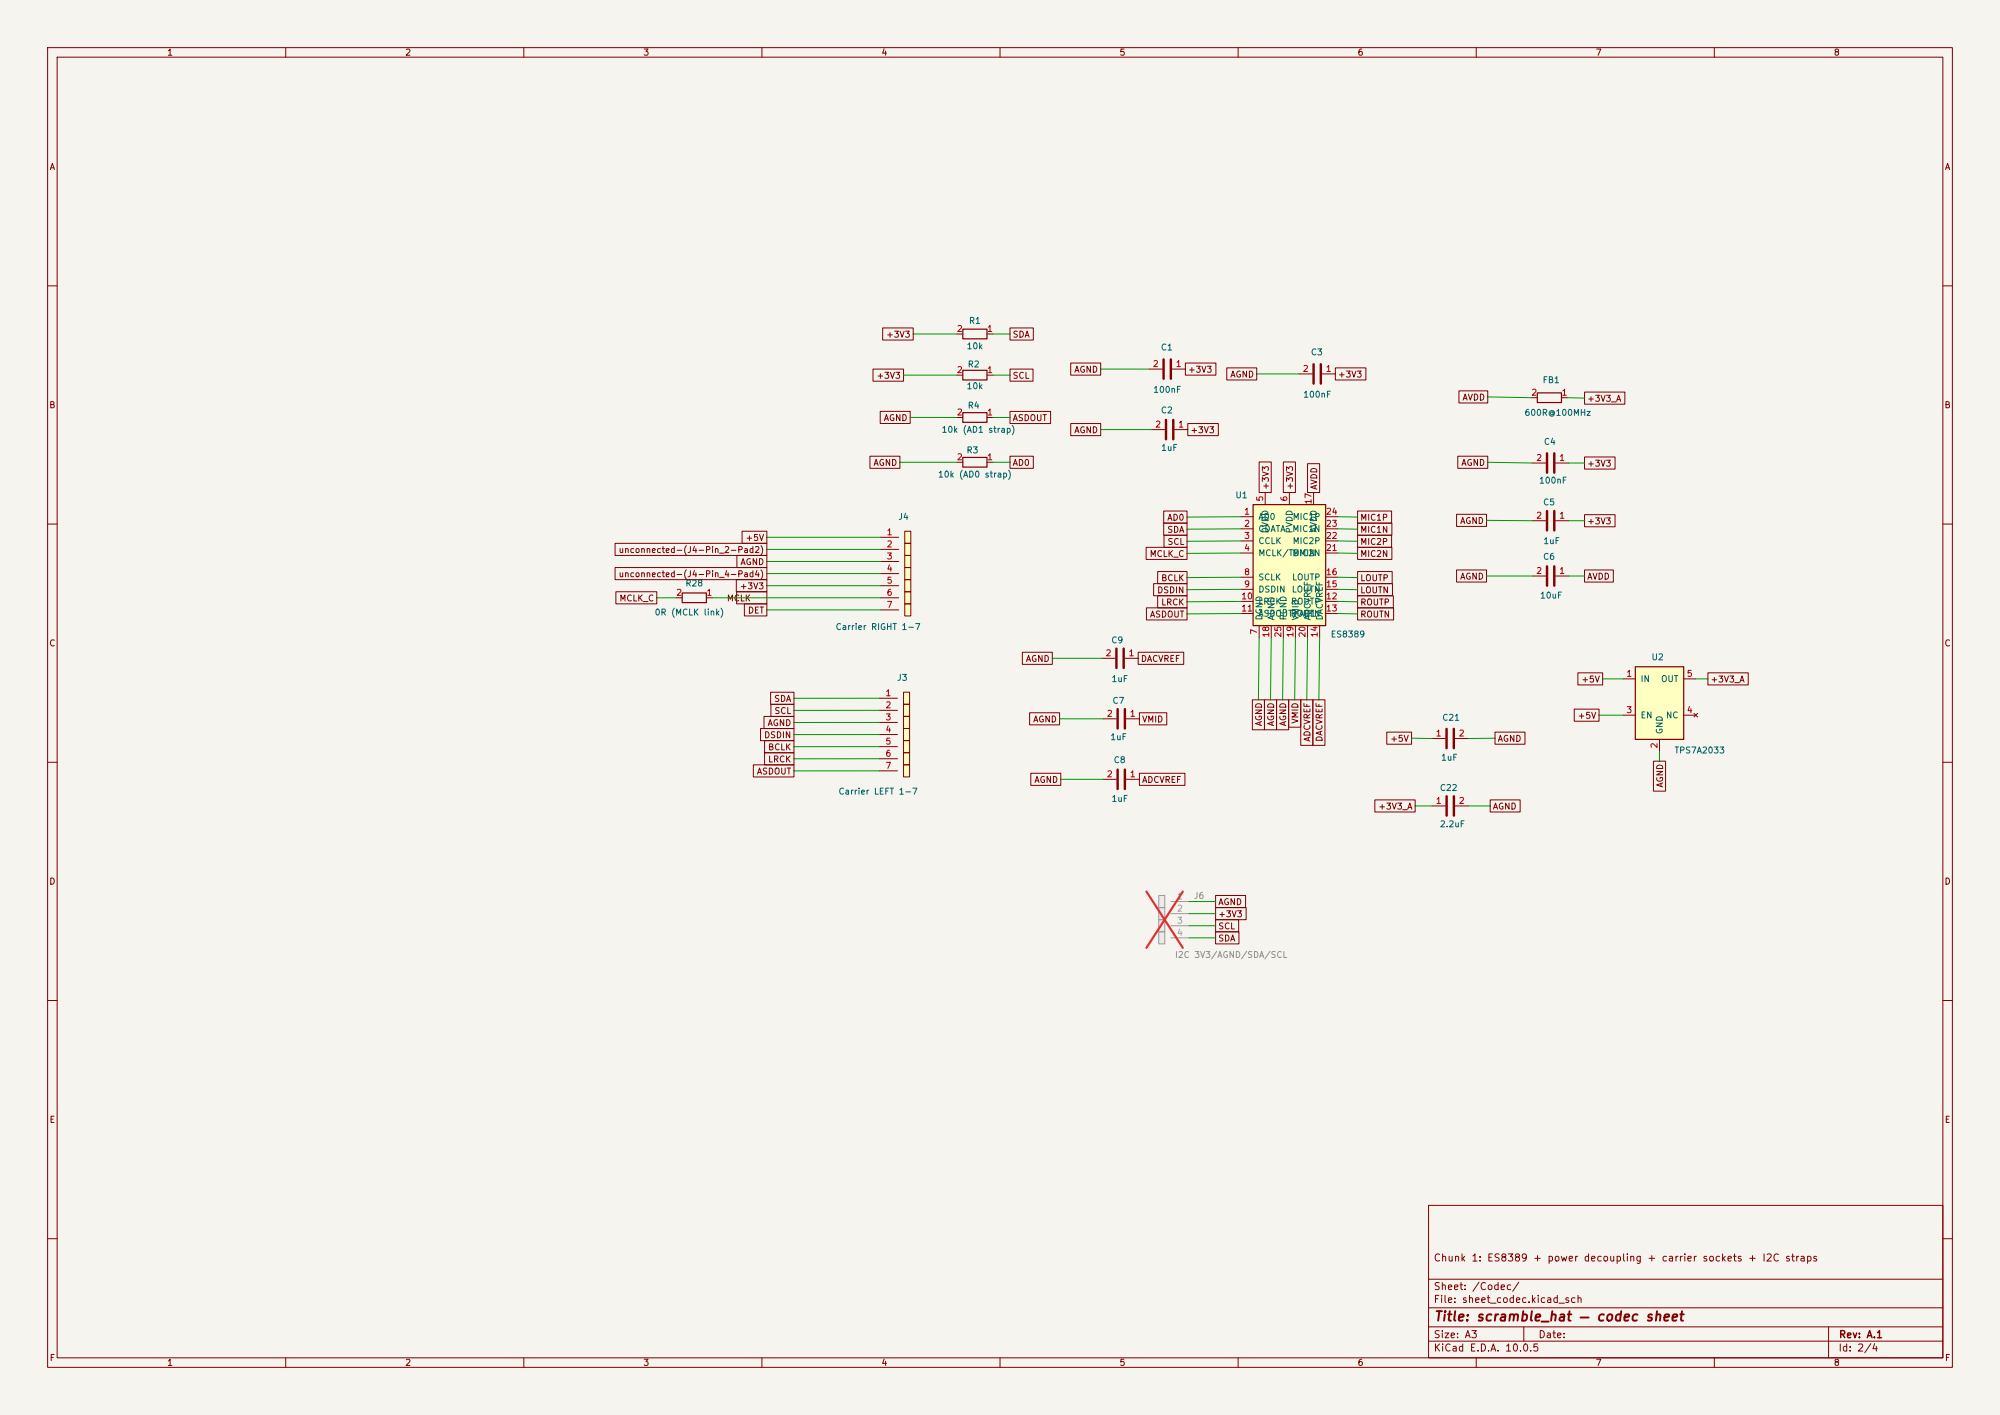
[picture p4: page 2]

Chunk 1: ES8389 + power decoupling + carrier sockets + I2C straps

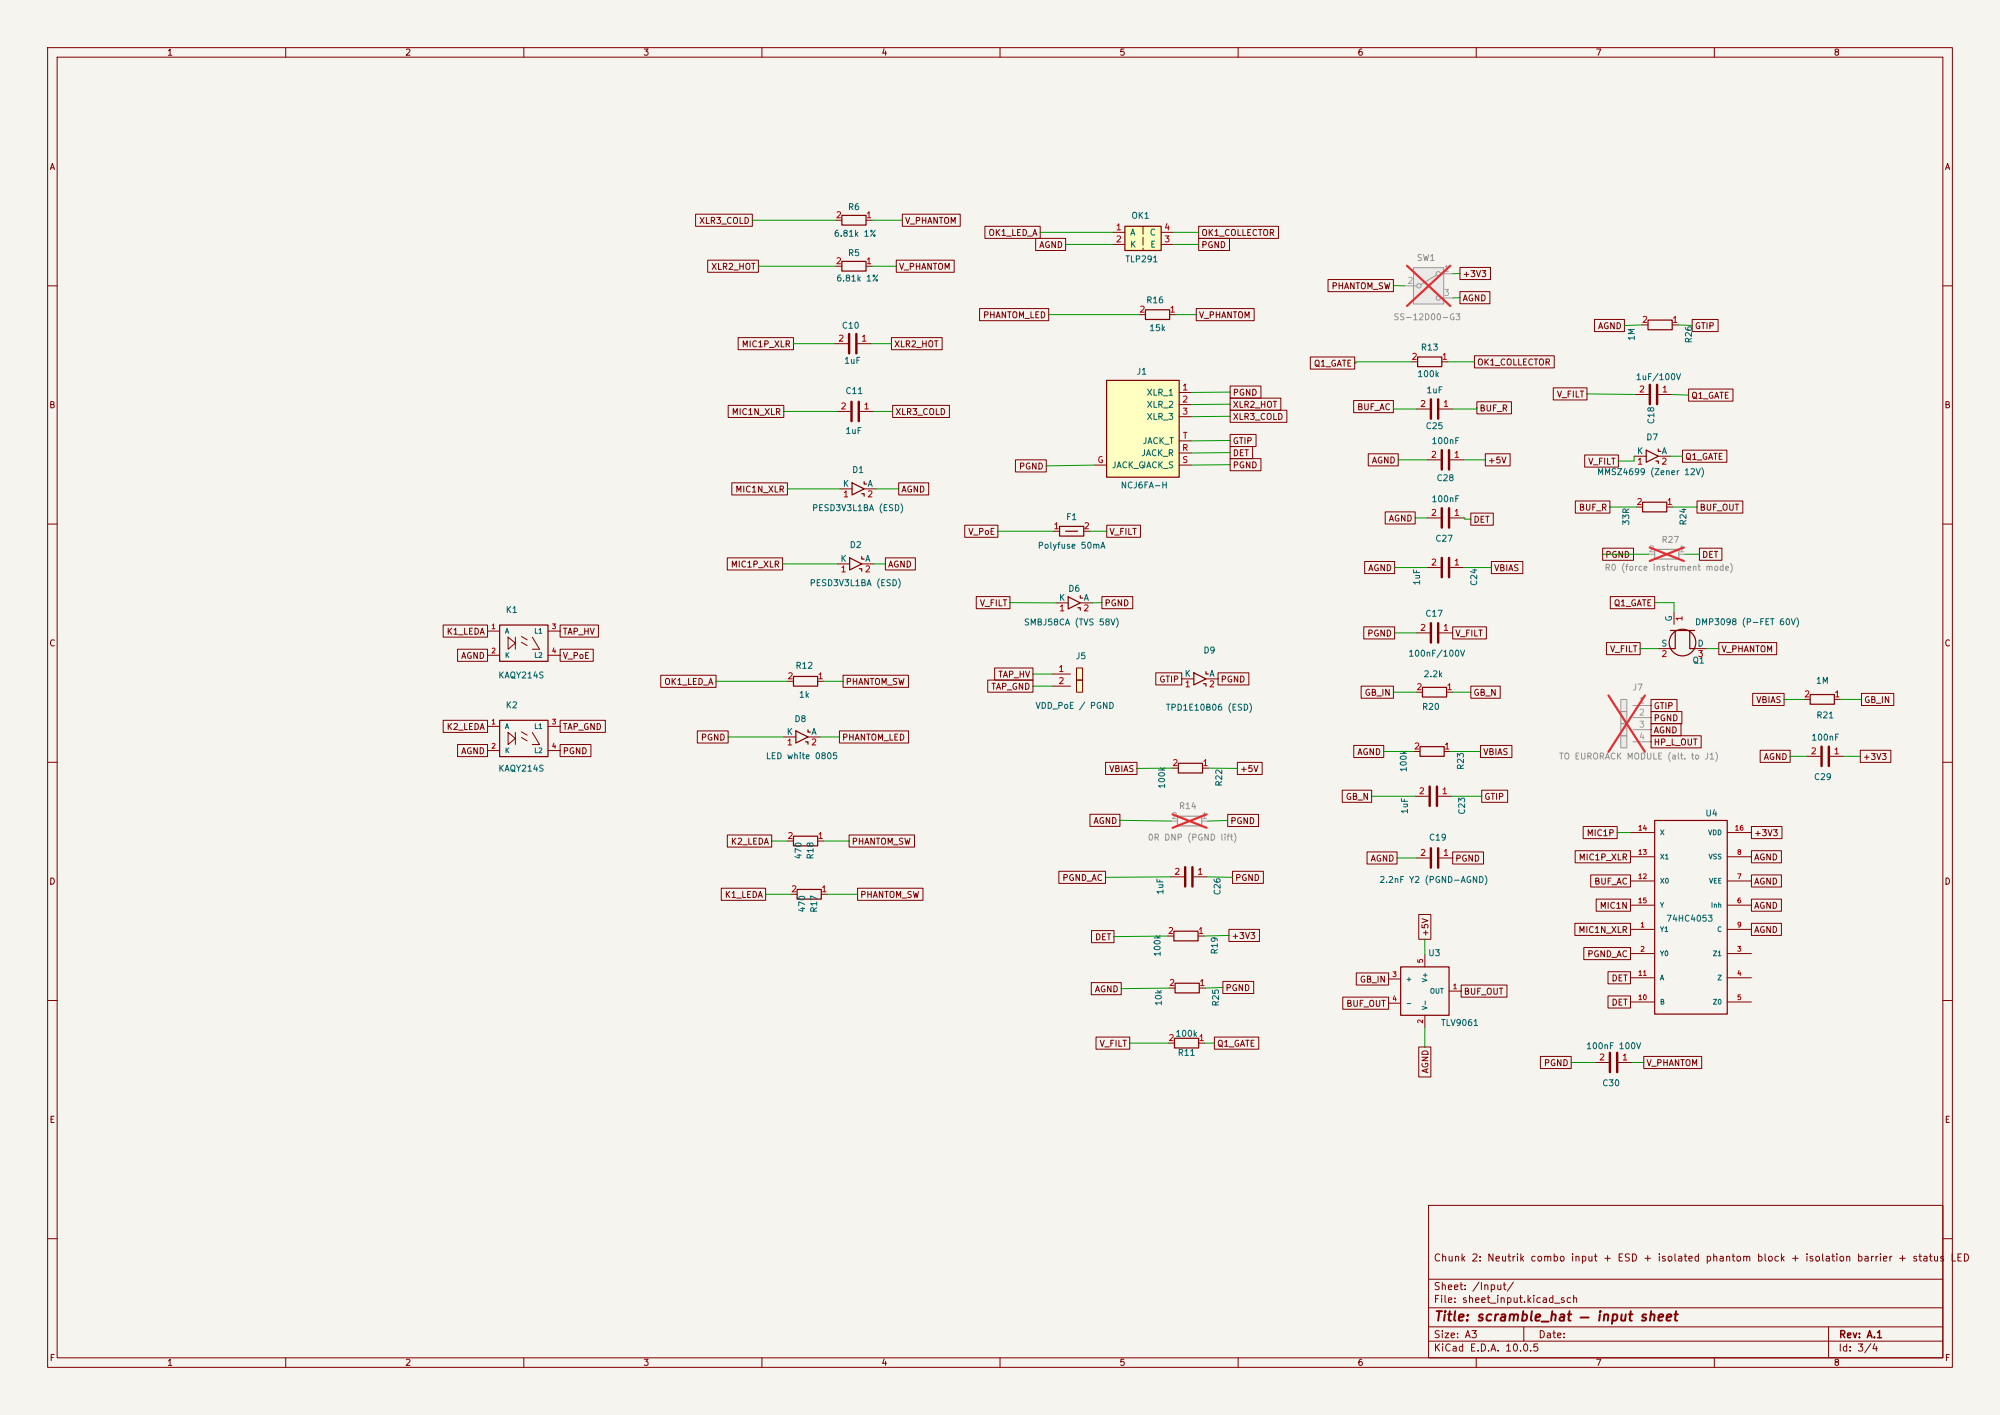
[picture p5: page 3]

TO EURORACK MODULE (alt. to J1) HP_L_OUT PGND +3V3 Q1_GATE

Chunk 2: Neutrik combo input + ESD + isolated phantom block + isolation barrier + status LED

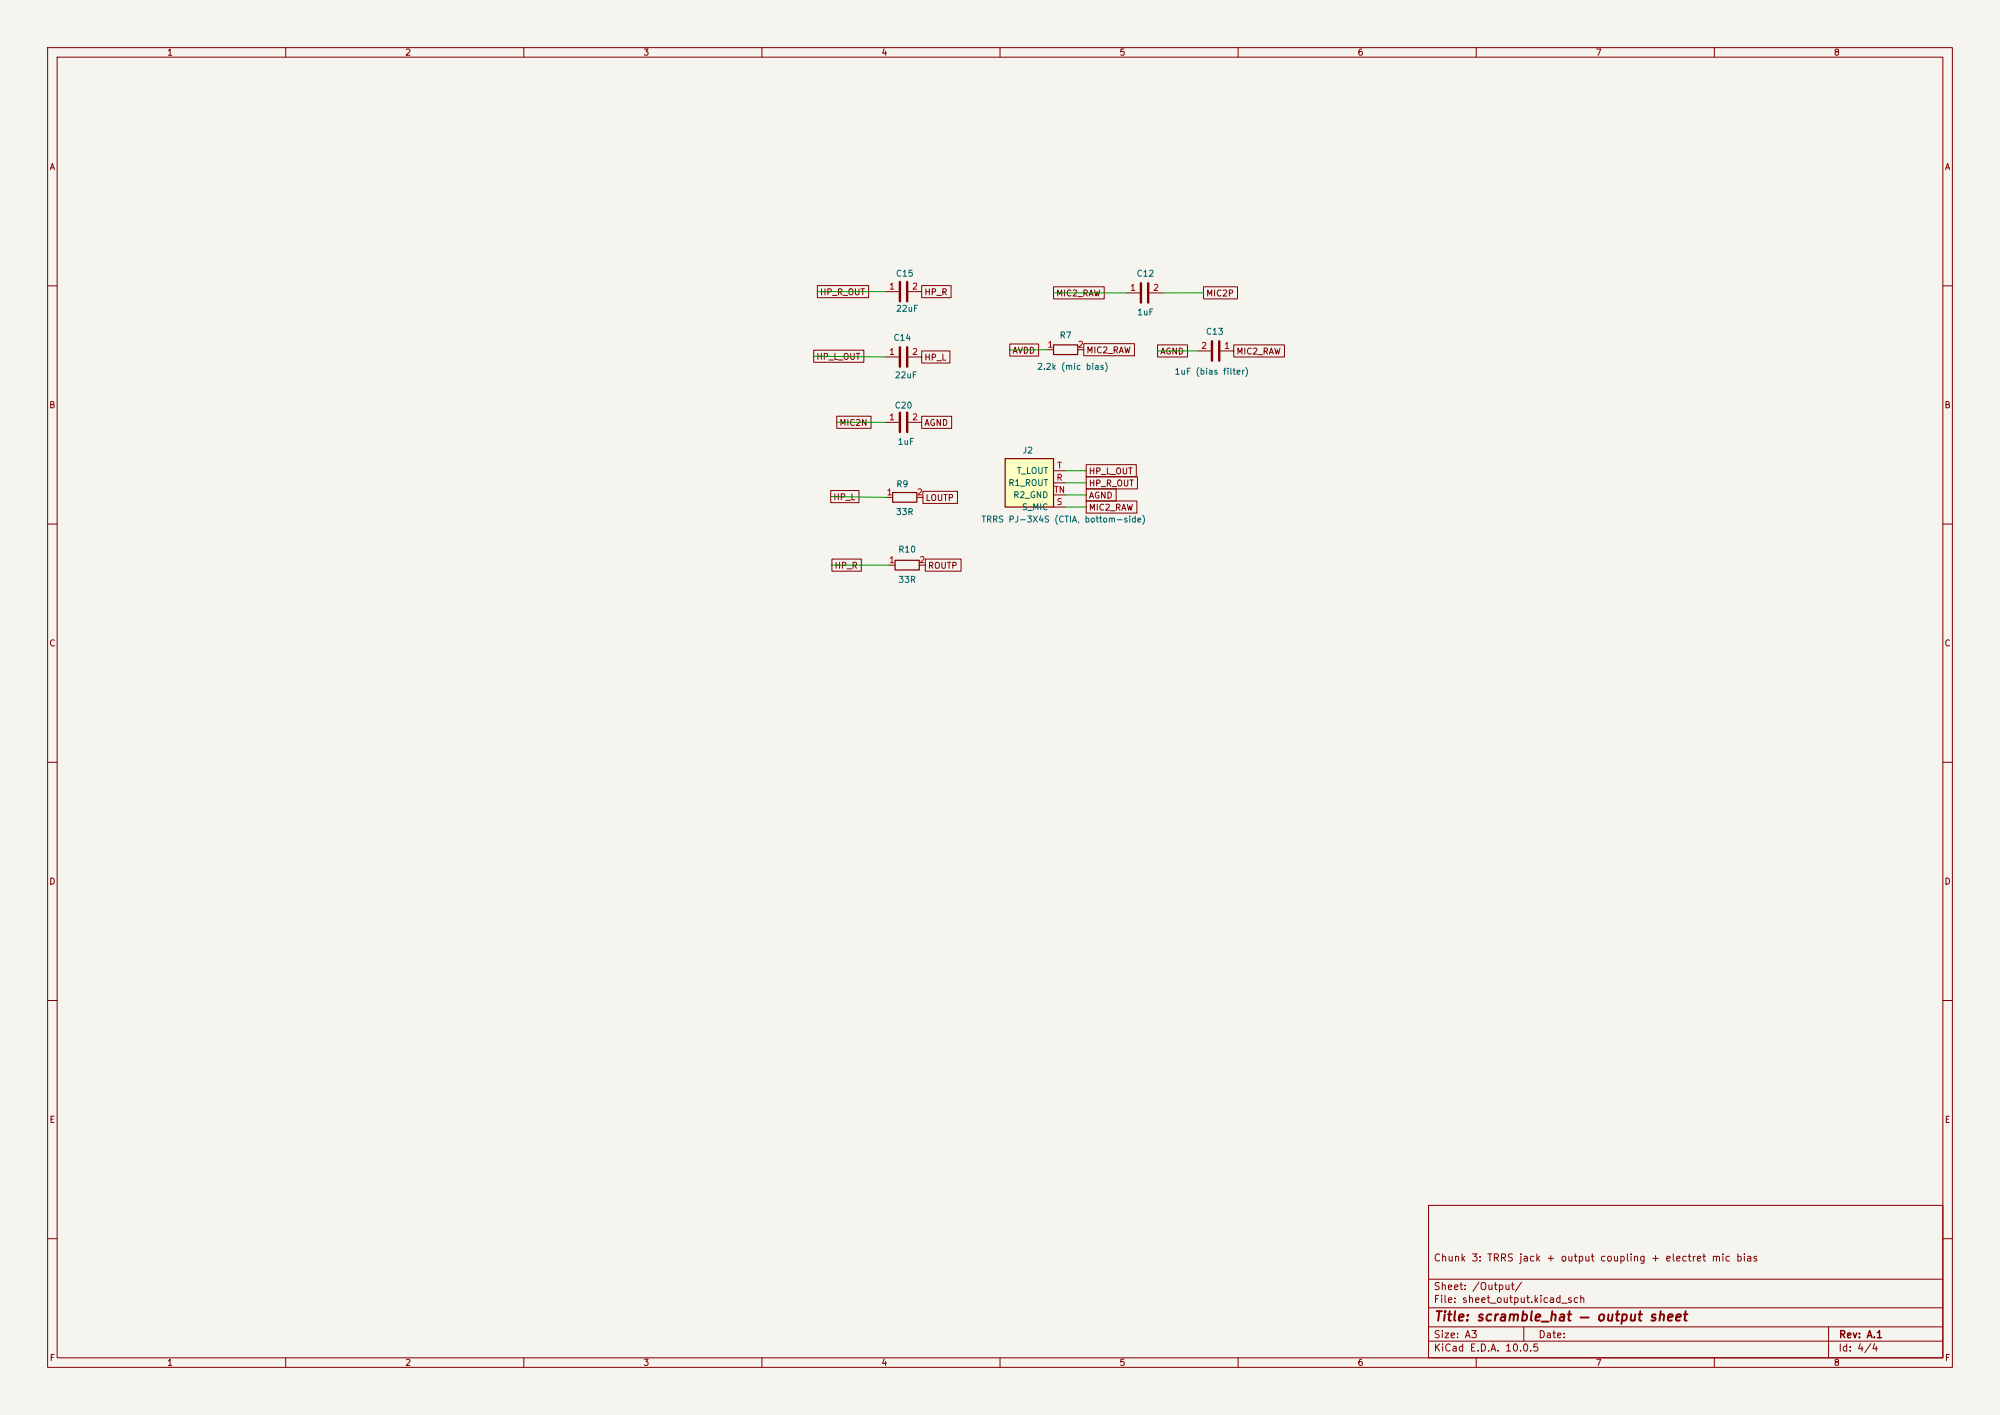
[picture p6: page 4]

Chunk 3: TRRS jack + output coupling + electret mic bias

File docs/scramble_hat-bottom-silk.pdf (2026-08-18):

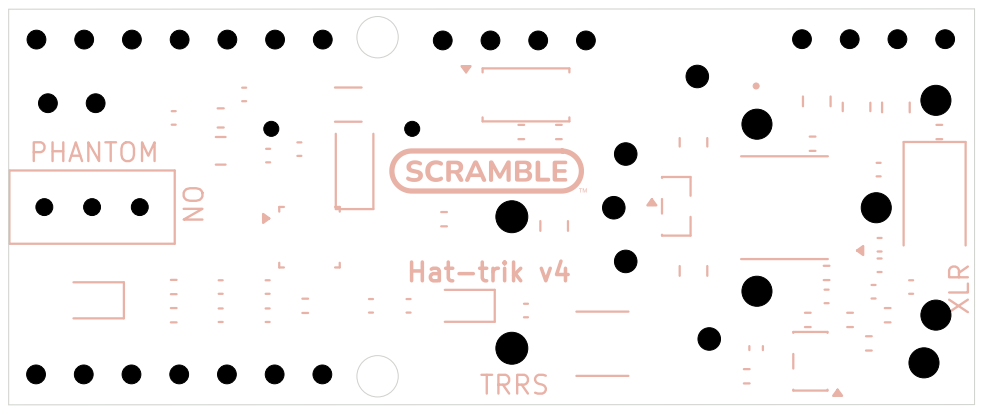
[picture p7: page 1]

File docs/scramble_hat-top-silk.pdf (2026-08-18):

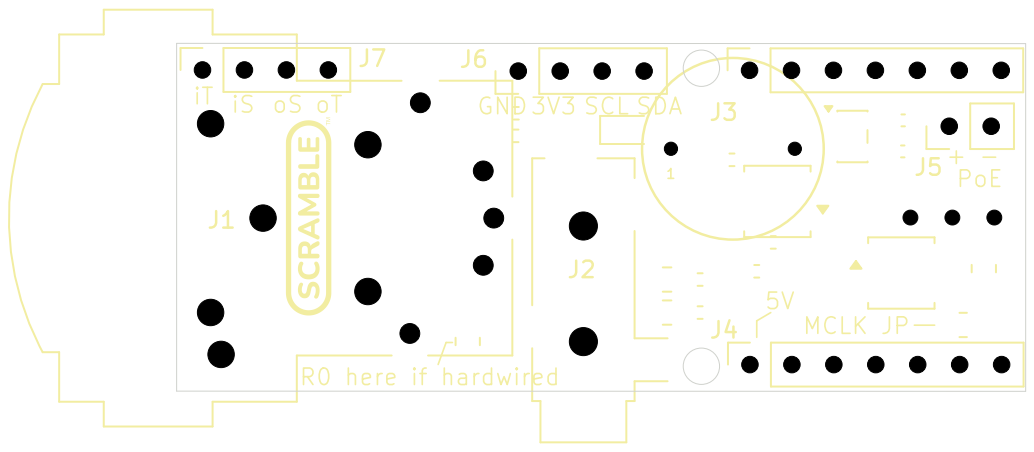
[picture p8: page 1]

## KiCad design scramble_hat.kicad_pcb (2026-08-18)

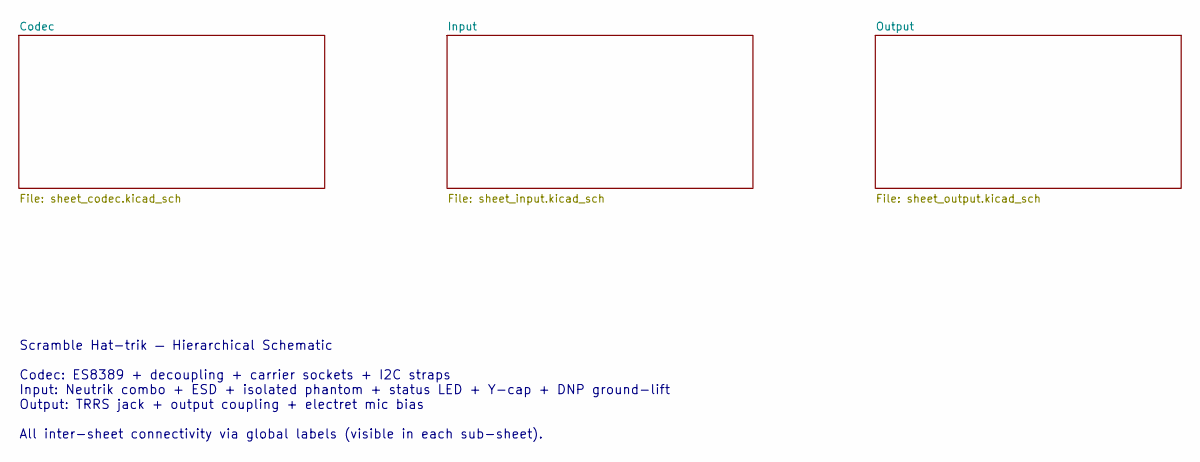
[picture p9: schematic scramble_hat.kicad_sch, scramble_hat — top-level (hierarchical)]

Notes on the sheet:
Scramble Hat-trik — Hierarchical Schematic Codec: ES8389 + decoupling + carrier sockets + I2C straps Input: Neutrik combo + ESD + isolated phantom + status LED + Y-cap + DNP ground-lift Output: TRRS jack + output coupling + electret mic bias All inter-sheet connectivity via global labels (visible i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

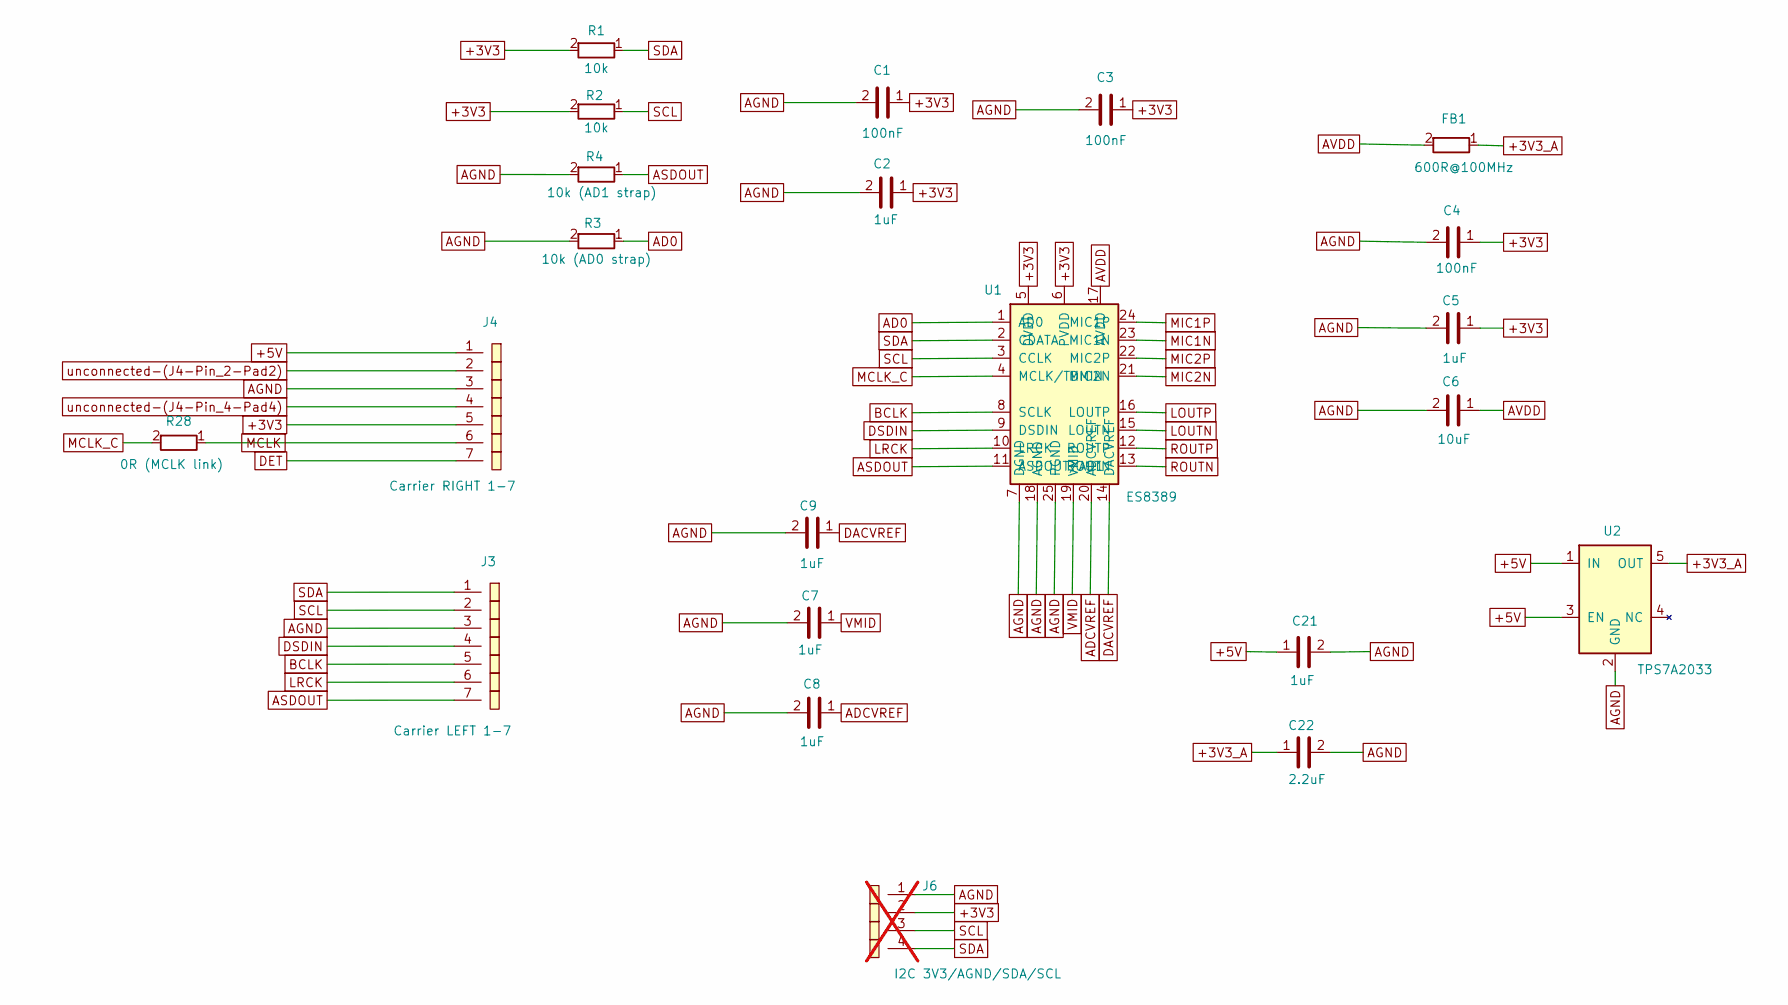
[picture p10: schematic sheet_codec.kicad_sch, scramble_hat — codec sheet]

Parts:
C1, C3, C4: 100nF; C_0402_1005Metric
C2, C5, C7, C8, C9, C21: 1uF; C_0402_1005Metric
C6: 10uF; C_0805_2012Metric
C22: 2.2uF; C_0402_1005Metric
FB1: 600R@100MHz; L_0603_1608Metric
J3: Carrier LEFT 1-7; PinSocket_1x07_P2.54mm_Vertical
J4: Carrier RIGHT 1-7; PinSocket_1x07_P2.54mm_Vertical
J6: I2C 3V3/AGND/SDA/SCL; PinHeader_1x04_P2.54mm_Vertical; not fitted
R1, R2: 10k; R_0402_1005Metric
R3: 10k (AD0 strap); R_0402_1005Metric
R4: 10k (AD1 strap); R_0402_1005Metric
R28: 0R (MCLK link); R_0805_2012Metric
U1: ES8389; ES8389_QFN24_P0.35mm
U2: TPS7A2033; SOT-23-5

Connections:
+3V3: C1.1, C2.1, C3.1, C4.1, C5.1, J4.5, J6.2, R1.2, R2.2, U1.5 (DVDD), U1.6 (PVDD); also elsewhere on the board
+3V3_A: C22.1, FB1.1, U2.5 (OUT)
+5V: C21.1, J4.1, U2.1 (IN), U2.3 (EN); also elsewhere on the board
AD0: R3.1, U1.1 (AD0)
ADCVREF: C8.1, U1.20 (ADCVREF)
AGND: C1.2, C2.2, C3.2, C4.2, C5.2, C6.2, C7.2, C8.2, C9.2, C21.2, C22.2, J3.3, J4.3, J6.1, R3.2, R4.2, U1.7 (DGND), U1.18 (AGND), U1.25 (PGND), U2.2 (GND); also elsewhere on the board
ASDOUT: J3.7, R4.1, U1.11 (ASDOUT/AD1)
AVDD: C6.1, FB1.2, U1.17 (AVDD); also elsewhere on the board
BCLK: J3.5, U1.8 (SCLK)
DACVREF: C9.1, U1.14 (DACVREF)
DET: J4.7; also elsewhere on the board
DSDIN: J3.4, U1.9 (DSDIN)
LOUTN: U1.15 (LOUTN)
LOUTP: U1.16 (LOUTP); also elsewhere on the board
LRCK: J3.6, U1.10 (LRCK)
MCLK: J4.6, R28.1
MCLK_C: R28.2, U1.4 (MCLK/TDMIN)
MIC1N: U1.23 (MIC1N); also elsewhere on the board
MIC1P: U1.24 (MIC1P); also elsewhere on the board
MIC2N: U1.21 (MIC2N); also elsewhere on the board
MIC2P: U1.22 (MIC2P); also elsewhere on the board
ROUTN: U1.13 (ROUTN)
ROUTP: U1.12 (ROUTP); also elsewhere on the board
SCL: J3.2, J6.3, R2.1, U1.3 (CCLK)
SDA: J3.1, J6.4, R1.1, U1.2 (CDATA)
VMID: C7.1, U1.19 (VMID)

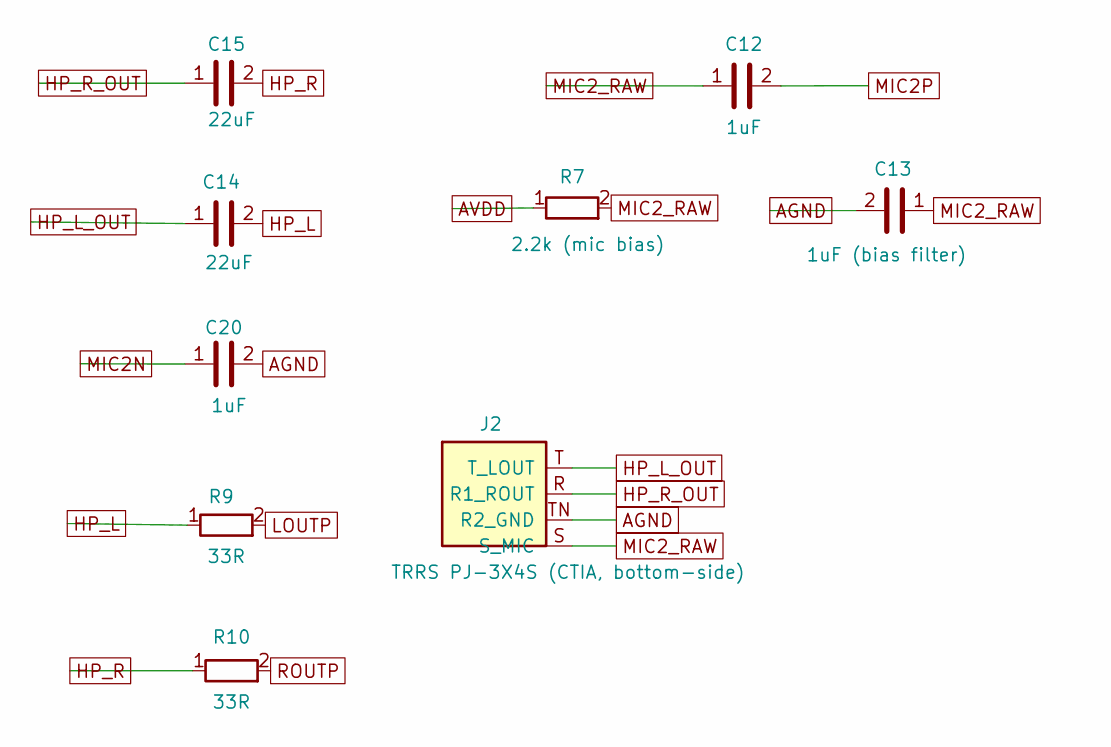
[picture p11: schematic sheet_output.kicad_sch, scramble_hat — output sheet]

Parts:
C12, C20: 1uF; C_0402_1005Metric
C13: 1uF (bias filter); C_0402_1005Metric
C14, C15: 22uF; C_0805_2012Metric
J2: TRRS PJ-3X4S (CTIA, bottom-side); Jack_3.5mm_CUI_SJ-3524-SMT_Horizontal
R7: 2.2k (mic bias); R_0402_1005Metric
R9, R10: 33R; R_0402_1005Metric

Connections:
AGND: C13.2, C20.2, J2.TN (R2_GND); also elsewhere on the board
AVDD: R7.1; also elsewhere on the board
HP_L: C14.2, R9.1
HP_L_OUT: C14.1, J2.T (T_LOUT); also elsewhere on the board
HP_R: C15.2, R10.1
HP_R_OUT: C15.1, J2.R (R1_ROUT)
LOUTP: R9.2; also elsewhere on the board
MIC2N: C20.1; also elsewhere on the board
MIC2P: C12.2; also elsewhere on the board
MIC2_RAW: C12.1, C13.1, J2.S (S_MIC), R7.2
ROUTP: R10.2; also elsewhere on the board

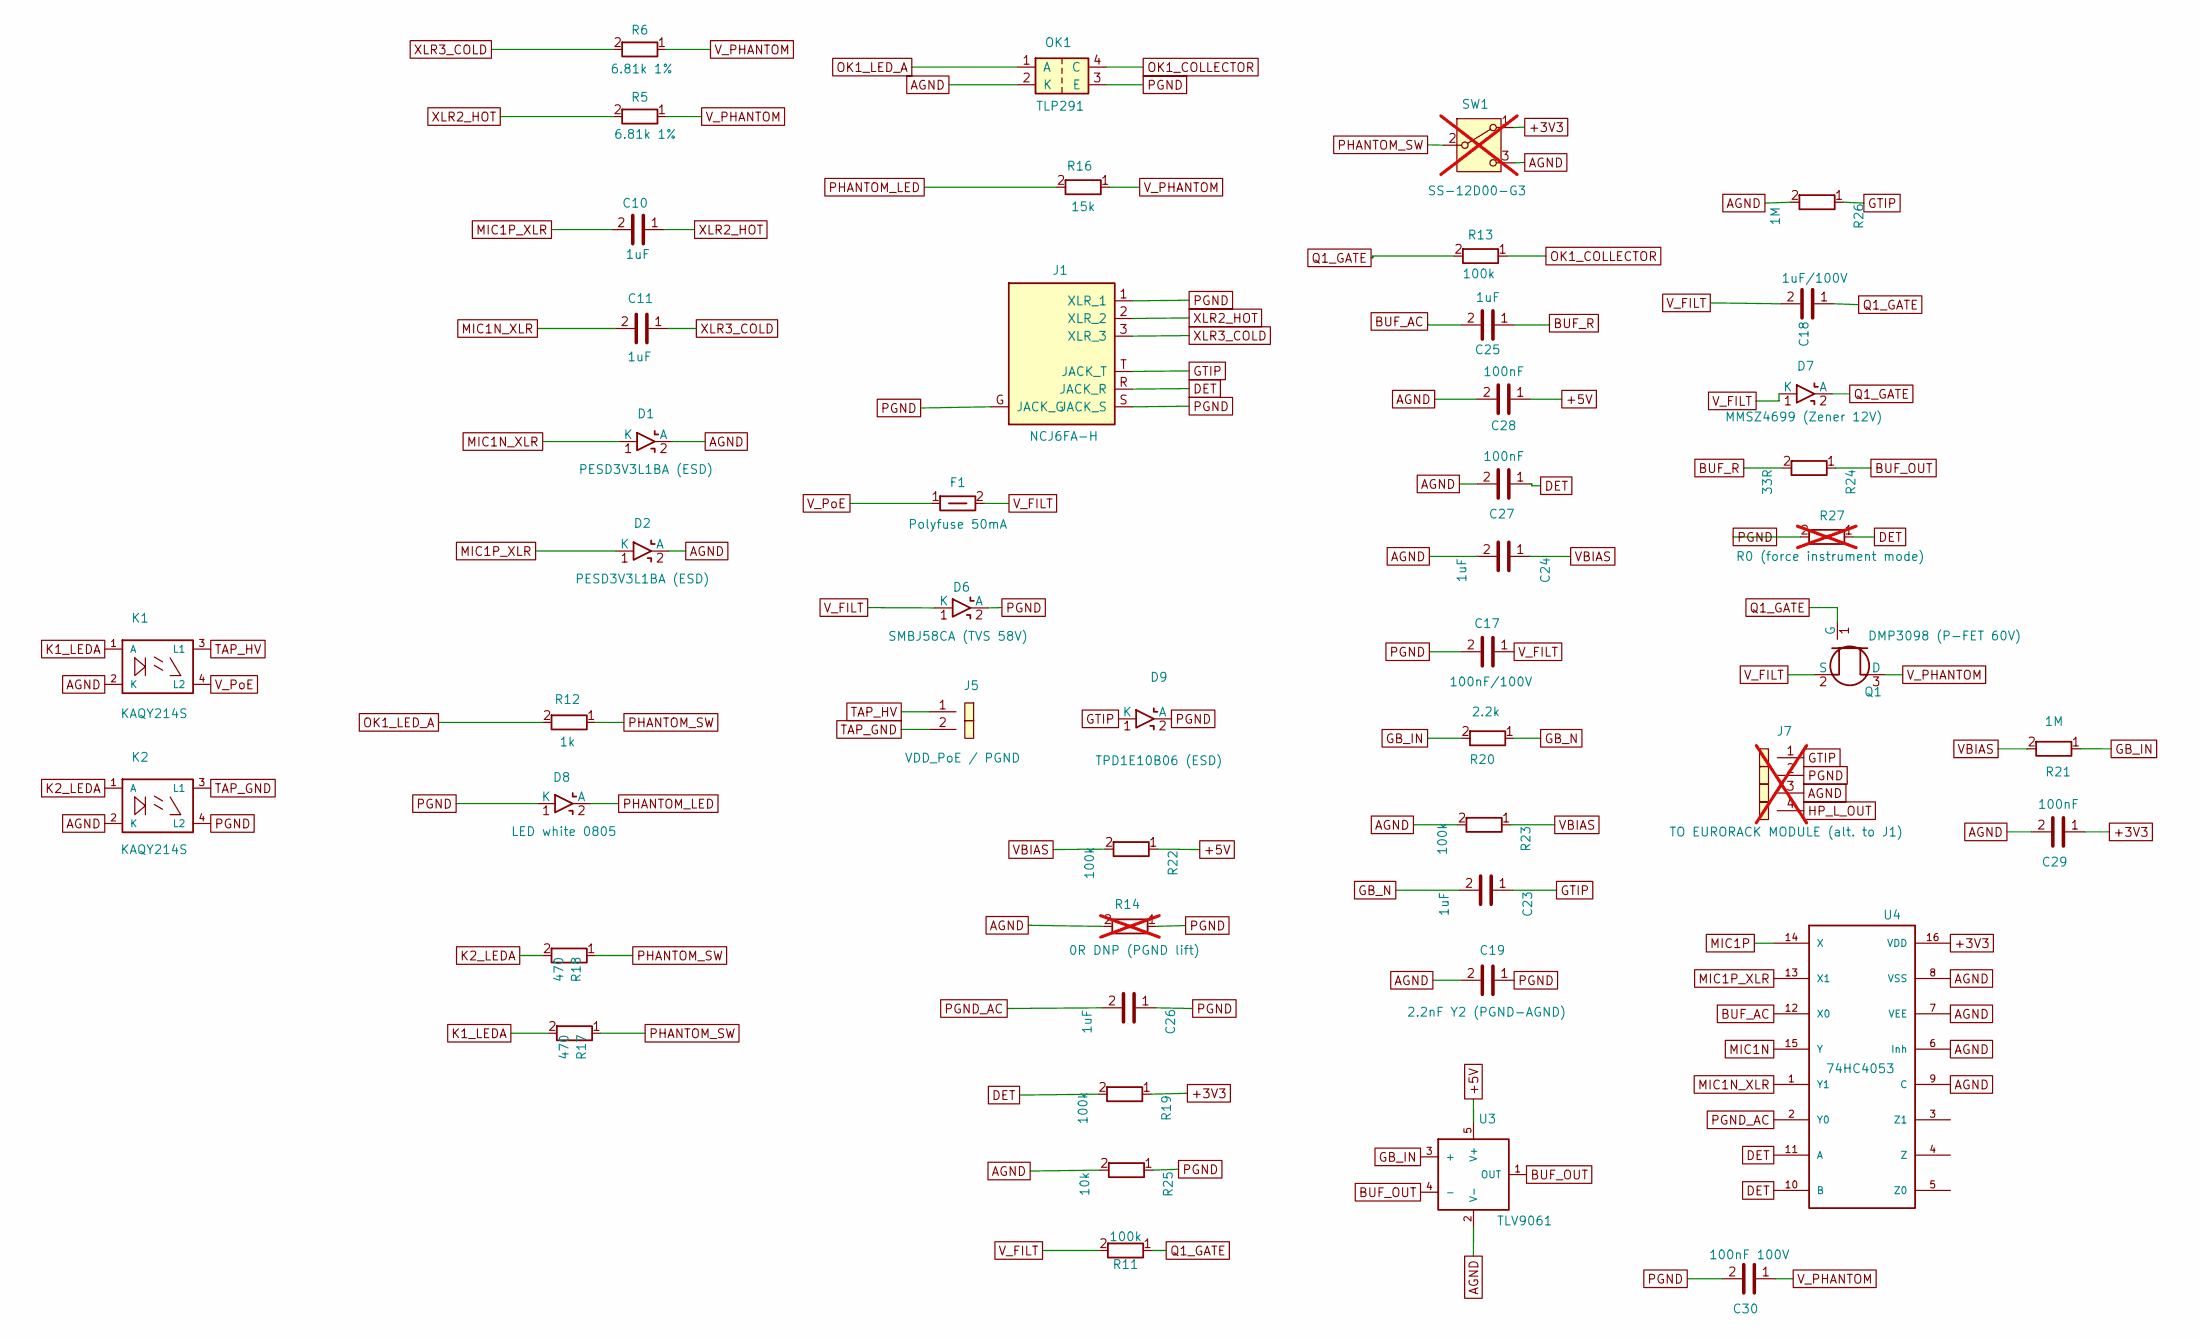
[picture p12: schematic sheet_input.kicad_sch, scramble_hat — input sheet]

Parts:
C10, C11: 1uF; C_0805_2012Metric
C17: 100nF/100V; C_0805_2012Metric
C18: 1uF/100V; C_1206_3216Metric
C19: 2.2nF Y2 (PGND-AGND); C_Y2_DE2B_TH
C23, C24, C25, C26: 1uF; C_0402_1005Metric
C27, C28, C29: 100nF; C_0402_1005Metric
C30: 100nF 100V; C_0805_2012Metric
D1, D2: PESD3V3L1BA (ESD); D_SOD-323
D6: SMBJ58CA (TVS 58V); D_SMA
D7: MMSZ4699 (Zener 12V); D_SOD-123
D8: LED white 0805; LED_0805_2012Metric
D9: TPD1E10B06 (ESD); Texas_DPY0002A_0.6x1mm_P0.65mm
F1: Polyfuse 50mA; Fuse_1812_4532Metric
J1: NCJ6FA-H; Jack_XLR-6.35mm_Neutrik_NCJ6FA-H_Horizontal
J5: VDD_PoE / PGND; PinHeader_1x02_P2.54mm_Vertical
J7: TO EURORACK MODULE (alt. to J1); PinSocket_1x04_P2.54mm_Vertical; not fitted
K1, K2: KAQY214S; SOP-4_3.8x4.1mm_P2.54mm
OK1: TLP291; SOP-4_4.4x2.6mm_P1.27mm
Q1: DMP3098 (P-FET 60V); SOT-23
R5, R6: 6.81k 1%; R_0805_2012Metric
R11, R13, R19, R22, R23: 100k; R_0402_1005Metric
R12: 1k; R_0402_1005Metric
R14: 0R DNP (PGND lift); R_0402_1005Metric; not fitted
R16: 15k; R_0805_2012Metric
R17, R18: 470; R_0402_1005Metric
R20: 2.2k; R_0402_1005Metric
R21, R26: 1M; R_0402_1005Metric
R24: 33R; R_0402_1005Metric
R25: 10k; R_0402_1005Metric
R27: R0 (force instrument mode); R_0805_2012Metric; not fitted
SW1: SS-12D00-G3; SW_Slide_SS-12D00-G3; not fitted
U3: TLV9061; SOT-23-5
U4: 74HC4053; TSSOP-16_4.4x5mm_P0.65mm

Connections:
+3V3: C29.1, R19.1, SW1.1 (A), U4.16 (VDD); also elsewhere on the board
+5V: C28.1, R22.1, U3.5 (V+); also elsewhere on the board
AGND: C19.2, C24.2, C27.2, C28.2, C29.2, D1.2 (A), D2.2 (A), J7.3, K1.2 (K), K2.2 (K), OK1.2 (K), R14.2, R23.2, R25.2, R26.2, SW1.3 (C), U3.2 (V-), U4.6 (Inh), U4.7 (VEE), U4.8 (VSS), U4.9 (C); also elsewhere on the board
BUF_AC: C25.2, U4.12 (X0)
BUF_OUT: R24.1, U3.1 (OUT), U3.4 (-)
BUF_R: C25.1, R24.2
DET: C27.1, J1.R (JACK_R), R19.2, R27.1, U4.10 (B), U4.11 (A); also elsewhere on the board
GB_IN: R20.2, R21.1, U3.3 (+)
GB_N: C23.2, R20.1
GTIP: C23.1, D9.1 (K), J1.T (JACK_T), J7.1, R26.1
HP_L_OUT: J7.4; also elsewhere on the board
K1_LEDA: K1.1 (A), R17.2
K2_LEDA: K2.1 (A), R18.2
MIC1N: U4.15 (Y); also elsewhere on the board
MIC1N_XLR: C11.2, D1.1 (K), U4.1 (Y1)
MIC1P: U4.14 (X); also elsewhere on the board
MIC1P_XLR: C10.2, D2.1 (K), U4.13 (X1)
OK1_COLLECTOR: OK1.4 (C), R13.1
OK1_LED_A: OK1.1 (A), R12.2
PGND: C17.2, C19.1, C26.1, C30.2, D6.2 (A), D8.1 (K), D9.2 (A), J1.1 (XLR_1), J1.G (JACK_G), J1.S (JACK_S), J7.2, K2.4 (L2), OK1.3 (E), R14.1, R25.1, R27.2
PGND_AC: C26.2, U4.2 (Y0)
PHANTOM_LED: D8.2 (A), R16.2
PHANTOM_SW: R12.1, R17.1, R18.1, SW1.2 (B)
Q1_GATE: C18.1, D7.2 (A), Q1.1 (G), R11.1, R13.2
TAP_GND: J5.2, K2.3 (L1)
TAP_HV: J5.1, K1.3 (L1)
VBIAS: C24.1, R21.2, R22.2, R23.1
V_FILT: C17.1, C18.2, D6.1 (K), D7.1 (K), F1.2, Q1.2 (S), R11.2
V_PHANTOM: C30.1, Q1.3 (D), R5.1, R6.1, R16.1
V_PoE: F1.1, K1.4 (L2)
XLR2_HOT: C10.1, J1.2 (XLR_2), R5.2
XLR3_COLD: C11.1, J1.3 (XLR_3), R6.2

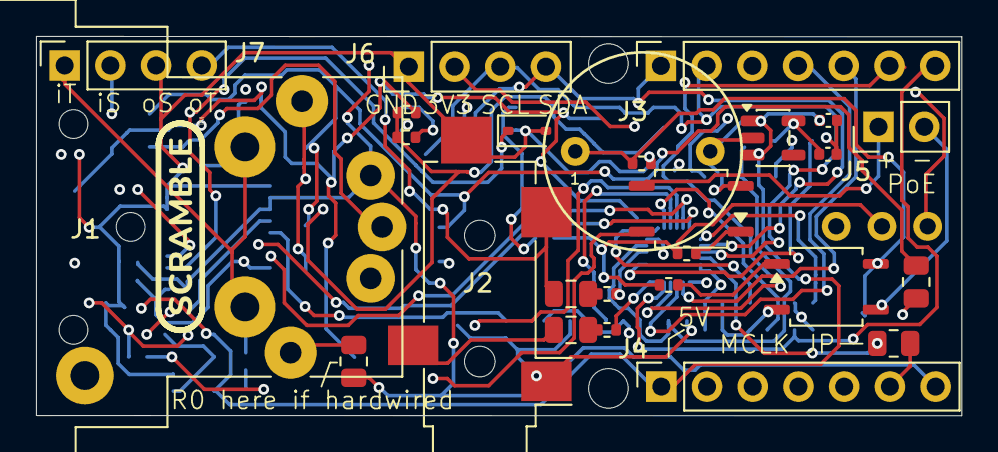
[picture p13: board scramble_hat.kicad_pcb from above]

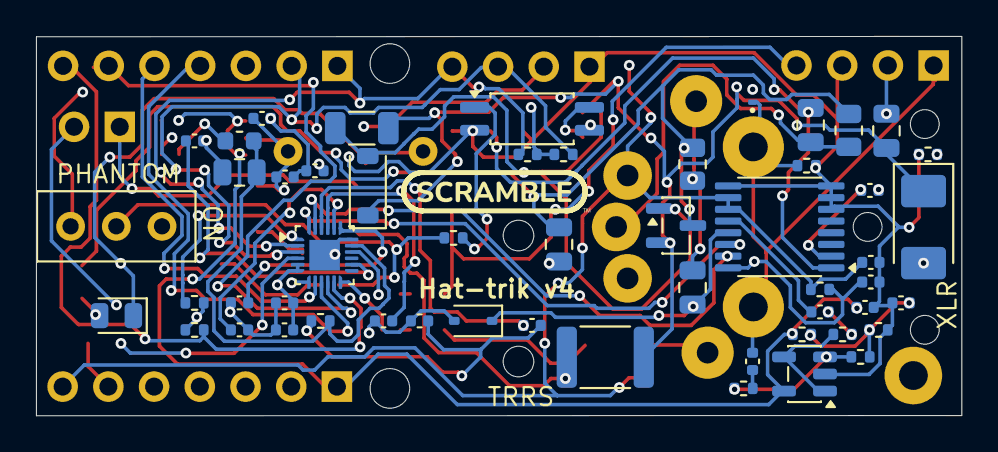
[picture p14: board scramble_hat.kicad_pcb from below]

Board: 4 copper layers, 51.4 x 21.1 mm, 79 parts (53 on the bottom side), 54 nets.

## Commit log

2026-05-31 init: first commit of the hat design
    [scramble_hat.dsn, scramble_hat.kicad_pcb, scramble_hat.kicad_sch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]
2026-06-19 design: full iteration since init — codec, phantom/PoE, LDO, BOM, fab
    First substantive commit since init; captures the entire design
    iteration and quiets KiCad churn in-repo.
    Codec / PCB
    - ES8389: custom QFN-24 0.35mm land pattern (ES8389_QFN24_P0.35mm)
    - Corrected mirror-reversed codec I2C/I2S pins
    - Un-mirrored all B.Cu footprints that imported un-flipped
    (U1, OK1, Q1, D2, D6-D8 + silk)
    - Re-coupled schematic to PCB netlist -> IN SYNC
    Phantom / PoE
    - F1 -> 1812L010/60DR (100mA hold / 60V, true 1812)
    - Q1 -> Si2325DS (150V) for PoE++ margin
    - Added SW1 SS-12D00-G3 slide switch = manual phantom enable (frees GPIO15)
    - D8/R15/R16 phantom-present LED rework
    - Confirmed PoE tap: BD1/BD2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
    [BOM.csv, Sample-BOM_JLCSMT.xlsx, scramble_hat-BOM.csv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]
2026-06-24 pcb: move D1 clear of J2 TRRS courtyard; refill zones
    D1 (MIC1N ESD, SOT-353) was overlapping the SJ-3524 TRRS jack
    courtyard; relocated to (107.9, 85.9), ~10mm clear of J2. Refilled
    zones so PGND_phantom carves clearance around D1's AGND/MIC1N fan-out
    vias.
    DRC: 0 errors, 0 unconnected, 0 courtyard overlaps.
    [scramble_hat.kicad_pcb]
2026-06-24 fab: regenerate gerbers, drill & CPL for D1 move
    Re-plotted from the DRC-clean board after relocating D1 clear of the
    J2 TRRS courtyard and refilling zones. Updated gerbers (D1 pads, PGND
    zone reflow on In1/B.Cu), drill, gerbers.zip, and CPL (D1 -> 107.899,
    -85.867; all other parts unchanged). BOM unchanged (no part changes).
    [scramble_hat-B_Cu.gbr, scramble_hat-B_Mask.gbr, scramble_hat-B_Paste.gbr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]
2026-06-24 lib: replace C19 Y2 cap with available Murata DE2E3SA222MA3BT02F
    Old DE2E3KY222MA3BM02F (LCSC C161048) is EOL/unavailable. Swap to
    DE2-SA series DE2E3SA222MA3BT02F (LCSC C524537) — same 2.2nF 250VAC
    X1/Y2, same 7.5mm-pitch TH land, so footprint is unchanged.
    - BOM.csv: MPN, LCSC#, price (~$0.11@5+), notes
    - C_Y2_DE2B_TH.kicad_mod: descr + datasheet -> Murata DE2-SA PDF
    - PCB embedded footprint descr synced (string-only; no geometry/net/
    fab change). DNP/TH part is excluded from SMT BOM/CPL, so fab outputs
    are unaffected.
    [BOM.csv, scramble_hat.kicad_pcb]
2026-06-24 lib: add representative 3D model for SW1 (SS-12D00-G3 slide switch)
    The SW_Slide_SS-12D00-G3 footprint had no (model ...) line, so SW1
    showed nothing in the 3D viewer. Add a dimensionally-representative
    VRML model (black body ~8.8x3.9x3.4mm + slider actuator + 3 leads,
    2.54mm pitch) for clearance/height checks.
    - lib/3dmodels/SS-12D00-G3.wrl (new; authored in mm, scale 0.3937 = 1/2.54)
    - SW_Slide_SS-12D00-G3.kicad_mod: (model ...) ref added
    - PCB embedded SW1 footprint: same (model ...) so it renders on the board
    Verified via kicad-cli pcb render (bottom): correct size + placement,
    body flips correctly for B.Cu. No fab impact (3D not in gerbers/CPL/BOM).
    [scramble_hat.kicad_pcb]
2026-06-24 lib: correct SW1 stem dimensions per SS-12D07 datasheet
    SS-12D07-VG/GA/PA datasheet (Documents/Specs) gives the actuator as a
    2.0mm-wide stem (front + side views), not the 2.8x1.6mm flat nub first
    modeled. The actuator height (L / "VG=") is left blank as the variant
    dimension; set stem protrusion to 3.0mm per visual proportion (~80-90%
    of body height). Stem now: 2.0 x 2.0mm square post + 0.4mm notched tip.
    Verified via kicad-cli pcb render.
2026-06-24 lib: convert SW1 switch model to STEP (unity scale) for STEP export
    KiCad's STEP exporter only embeds STEP/IGES models and warns on
    non-unity scaled models. The SW1 model was VRML referenced at scale
    0.3937 (VRML's 2.54mm-unit workaround), which triggered the
    "non-unity scaled model may produce unreliable results" warning and
    left the switch out of the STEP.
    Replace the .wrl with a hand-generated STEP B-rep (mm, same geometry:
    8.8x3.9x3.4mm body + 2x2mm/3mm stem + 0.4mm tip + 3 leads) and
    reference it at scale (1 1 1) in both the footprint and the embedded
    PCB instance. STEP works in the 3D viewer too, so the .wrl is removed.
    Verified: kicad-cli render shows a valid solid; STEP export now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
    [scramble_hat.kicad_pcb]
2026-07-07 case: track enclosure CAD; ignore whole-board STEP exports
    Add case/ enclosure model: Plasticity source (+ timestamped history
    snapshots) and eth-side / xlr-side STEP and 3MF exports.
    Ignore root-level whole-board STEP exports (/*.step, /*.stp); footprint
    models under lib/3dmodels/ and case geometry under case/ remain tracked.
    [barrel.3mf, eth-side.stp, xlr-side.3mf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]
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2026-07-09 fix: phantom drive — correct D7/OK1 orientation, 80V opto, drop C16
    - D7 zener was reversed (Vgs clamped at -0.7V, FET never switched);
    cathode now to V_FILT, anode to Q1_GATE.
    - OK1 optocoupler C/E were swapped in the symbol (pin3/pin4), exceeding
    its 6V emitter-collector reverse rating on the PoE rail and holding
    phantom on in both switch positions; collector->R13/gate, emitter->PGND.
    - OK1 -> TLP291 (80V Vceo), SOP-4 1.27mm; LTV-817's 35V was under-rated
    for the 46-57V PoE rail.
    - Remove C16 (10uF): it sat on the tapped bus and broke 802.3 PoE
    detection (>0.15uF), which blocked cold-start with the tap connected.
    - Regenerate fab set (gerbers, drills, CPL, BOM) for the above.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
    [BOM.csv, scramble_hat-BOM.csv, scramble_hat-BOM.xlsx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]
2026-07-09 codec: add J6 4-pin I2C header (3V3/AGND/SDA/SCL) for external display
    - New scramble_hat:Conn_01x04 symbol + J6 in sheet_codec, connected to
    +3V3/AGND/SDA/SCL; placed on F.Cu and routed.
    - Pin order (AGND/+3V3/SCL/SDA) set to match the external display's
    wiring harness.
    - Fab set intentionally NOT regenerated (more design changes pending).
    [scramble_hat.kicad_pcb, sheet_codec.kicad_sch, sheet_input.kicad_sch]
2026-07-09 case: remove obsolete barrel/xlr-side 3MF exports
    [barrel.3mf, xlr-side.3mf]
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2026-07-10 fab: production prep — white/brighter status LED, C19 assembled, live BOM prices
    - D8 red -> white: KT-0805W (C34499, Basic, in stock); old Kingbright
    KP-2012EC (C598272) was out of stock.
    - R16 33k -> 15k, 1/4W AC0805 (C20142753) — ~2x brighter phantom-present
    LED (~3mA); resistor dissipates ~193mW at the 57V PoE max.
    - C19 -> JEC JY222M2FY5VS7LE (C389727, Y2 300VAC, same 7.5mm land, in
    stock) moved onto JLCPCB THT assembly (off the hand-solder list).
    - exclude_from_pos_files on J1/J2/J5 so placement/CPL leaves the
    hand-soldered parts (jacks + PoE header) to hand assembly.
    - BOM: added J6, filled all resistor LCSC#s, refreshed unit prices to
    live qty-10 LCSC, corrected the D1/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
    [BOM.csv, scramble_hat-BOM.csv, scramble_hat-BOM.xlsx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]
2026-07-10 fab: remove dangling track stubs; regenerate gerbers
    - Cleaned up 2 zero-length dangling track fragments (LRCK, +3V3) left
    from the J6 re-route.
    - Regenerated gerbers/drills/zip from the cleaned board.
    - DRC: 0 unconnected, no shorts/clearance errors (remaining warnings are
    cosmetic silkscreen + the benign PinSocket library mismatch).
    [scramble_hat-B_Cu.gbr, scramble_hat-B_Mask.gbr, scramble_hat-B_Paste.gbr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]
2026-07-10 fab: add reusable production-file generator (tools/gen_fab.py)
    One command (python3 tools/gen_fab.py) rebuilds gerbers, drills, zip, BOM (from BOM.csv with DNP rows dropped) and the CPL with JLCPCB rotation corrections. The CPL rotations were cross-validated against the Fabrication Toolkit plugin output and additionally apply the U1/QFN +270 correction the plugin's auto-rotation database misses (custom footprint name).
    - fab/scramble_hat-CPL.csv: committed placement file (49 parts; J1/J2/J5/R14 excluded via exclude_from_pos_files/dnp)
    - fab/README.md: regeneration + CPL sections now point at the script
    - .gitignore: ignore plugin scratch output (production/, fabrication-toolkit-options.json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
    [scramble_hat-CPL.csv]
2026-07-11 fab: resolve JLCPCB short-supply flags (OK1, C19, R1-R4)
    JLC flagged three parts short at qty-10; sourced in-stock fixes:
    - OK1: TLP291 (C393895) -> Everlight EL3H7(C)(TA)-G (C92243). Same SOP-4 1.27mm land + opto pinout, 80V Vceo -> pure BOM swap, no layout change.
    - C19: 2.2nF Y2 cap moved off the JLC line to hand-solder (every 7.5mm Y2 is thin at LCSC). Added exclude_from_pos_files in the PCB; BOM references Murata DE2E3SA222MA3BT02F for user sourcing.
    - R1-R4: C25744 (UNI-ROYAL 0402WGF1002TCE, out of stock) was mislabeled with a Yageo MPN; corrected to the matching Yageo C60490 (10k 0402 1%, in stock).
    Regenerated fab BOM (28 assembled parts) and CPL (48 placements; C19 now excluded al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
    [BOM.csv, scramble_hat-BOM.csv, scramble_hat-BOM.xlsx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]
2026-07-12 fab: enlarge sub-spec vias to 0.3 mm drill for JLCPCB
    Three vias were 0.1 mm drill / 0.3 mm pad — below JLCPCB's minimum. Enlarged to 0.3 mm drill / 0.6 mm pad and re-routed to suit; all 100 vias are now >= 0.3 mm drill. Netlist unchanged (check_sync: i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
    [scramble_hat-B_Cu.gbr, scramble_hat-B_Mask.gbr, scramble_hat-B_Paste.gbr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]
2026-07-12 docs: add project README describing the board and capabilities
    Root README: overview, capabilities, signal/power-flow, connector + key-component tables, board specs, host integration, repo layout, and a manufacturing pointer. Corrected the fab README board size to the measured 21.1 mm.
2026-07-12 sch: add datasheet links, hide Datasheet/Description fields, remove sentinel text
    - Filled 38 empty component Datasheet fields with LCSC product-page links (derived from the BOM part numbers); fixed D8's stale link (Kingbright KP-2012EC -> white KT-0805W / C34499). Existing manufacturer/distributor links kept.
    - Hid the Datasheet and Description fields on all 53 placed components (most were previously shown, cluttering the canvas).
    - Removed the 4 leftover sentinel text annotations.
    - Netlist unchanged (check_sync: in sync, 53 comps / 46 nets).
    [scramble_hat.kicad_sch, sheet_codec.kicad_sch, sheet_input.kicad_sch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]
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2026-07-14 update: hat part metadata and footprint fixes
    - add LCSC datasheet links to component properties
    - include a part in pos files (drop exclude_from_pos_files)
    - adjust a footprint property position
    [scramble_hat.kicad_pcb]
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2026-07-16 feat: phantom PoE-tap disconnect via SPDT + dual PhotoMOS
    Open both PoE-tap lines (V_PoE and PGND) when phantom is off so the
    Ethernet-referenced PoE ground stops coupling buzz into a dynamic mic.
    SW1 (SPDT) drives the Q1 enable plus two KAQY214S PhotoMOS SSRs (K1/K2)
    through R17/R18: K1 breaks V_PoE, K2 breaks PGND. Both lines must open
    because C17 (100nF) bridges them, so breaking one alone leaves the buzz.
    SMD PhotoMOS instead of a DPDT slide: the through-hole DPDT's pads cut
    through the inner-layer I2S/I2C bus (33 DRC shorts); the SOP-4 SSRs sit
    on one copper layer and route clean.
    sheet_input: SW1 back to SPDT; add K1/K2 (scramble_hat:PhotoMOS symbol,
    KiCad SOP-4_3.8x4.1 footprint)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
    [BOM.csv, scramble_hat-BOM.csv, scramble_hat-BOM.xlsx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]
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2026-07-16 pcb: reposition silkscreen; regen silk gerbers + doc PDFs
    Silk-layer only (nets/copper/CPL/BOM unchanged, still in sync). Regenerated F/B silkscreen gerbers + gerbers.zip and the docs PDFs.
    [scramble_hat.kicad_pcb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]
2026-07-16 pcb: hide component refdes on silk (keep J1-J6); align Fab values to reference positions
    Silk: reference designators hidden on all footprints except the six connectors (J1-J6, left visible for users). Fab: each Value moved to its reference's position + orientation (references and layers 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
    [scramble_hat.kicad_pcb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]
2026-07-21 feat: auto-detect Hi-Z guitar input (buffer + 4053 mux on MIC1)
    Add a high-impedance electric-guitar input that shares the codec's MIC1
    channel with the XLR mic and switches over automatically when a 1/4"
    plug is inserted.
    - Detect: the 1/4" jack is a TRS socket, so a mono guitar (TS) plug
    shorts the Ring to Sleeve/PGND. Ring pulled to +5V (R19) + debounce
    (C27) => DET low = "instrument".
    - Buffer U3 (TLV9061, +5V): ~1M input on the jack tip, unity follower;
    the codec PGA provides the level so no extra stage is needed. R20/R21
    input, R22/R23+C24 mid-rail bias, R24/C25 output.
    - Mux U4 (74HC4053, +5V): dual-SPDT picks the MIC1P/MIC1N source = XLR
    mic (no plug) or buffered guitar +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
    [BOM.csv, sheet_input.kicad_sch]
2026-07-21 fix: guitar-input detect ground path; consolidate values; add tip ESD
    The ring-detect as first committed could not work with phantom off: the
    hat's PGND (XLR shield, jack sleeve) reaches AGND only through
    capacitors (C19) and the DNP R14, so it floats at DC and the detect
    pull-up would drag the whole net high instead of reading the plug's
    ring-to-sleeve short. Add R25 (10k PGND->AGND bleed) to give the detect
    a DC return; DET now reads ~0.45V with a plug in. Side benefit: the XLR
    shield is no longer floating when the PoE tap is open (it now bleeds to
    audio ground), without recreating the low-impedance tap loop the
    PhotoMOS disconnect exists to break.
    Also:
    - Consolidate new-block values ont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
    [BOM.csv, sheet_input.kicad_sch]
2026-07-21 feat: expose guitar plug-detect to the carrier on J3.7
    Repurpose the dangling PHANTOM_EN line (vestigial since the manual SW1
    pivot) as a firmware readback of the guitar-detect signal: J3.7 now
    carries DET, so the carrier can see plug state (channel labeling,
    muting the mode-switch click).
    Instead of the planned 74HCT4053 swap -- no TSSOP-16 HCT4053 exists at
    LCSC/JLCPCB from any vendor -- keep the in-stock 74HC4053 (C5648) and
    run it from +3V3: VIH drops to 2.31V, so the 3.3V DET drives the select
    pins in spec, and the line is native 3.3V for the ESP32-P4's
    non-5V-tolerant GPIO. Analog range 0-3.3V covers the codec-bias-centred
    signals (worst case ~0.1-2.9V at guitar full-scale); Ron rises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
    [BOM.csv, sheet_codec.kicad_sch, sheet_input.kicad_sch]
2026-07-21 fix: register Package_SON footprint lib (D9 X1-SON-2 package)
2026-07-21 cost: D1/D2 ESD swap PESD3V3L4UG -> PESD3V3L1BA-N (C316020)
    Only 1 of the 4-line array's channels was in use on each part. The
    single-line SOD-323 bidirectional part is a better fit for the mV audio
    lines (symmetric clamp, no polarity/orientation for assembly), saves
    ~$0.14/board at 134k stock, and the 2-pin symbol now matches the part
    so the F8 pad-3/4/5 warnings go away. Phantom-transient clamping is
    equivalent. Footprint change SOT-353 -> D_SOD-323; re-place at layout.
    [BOM.csv, sheet_input.kicad_sch]
2026-07-21 fix: restore D8/R12 phantom-LED wiring swapped during schematic tidy-up
    A visual cleanup cross-attached two labels: D8's cathode return picked
    up OK1_LED_A while R12's output picked up PGND, putting the opto LED
    downstream of the rail it enables (phantom could never start) and
    leaving R12 driving ground. Swap the two labels back: R12 -> OK1 LED
    anode, D8 -> PGND. Netlist now matches the pre-tidy baseline exactly.
    [sheet_input.kicad_sch]
2026-07-22 pcb: place + route guitar input; regen fab
    Layout for the guitar-input rev (U3 buffer, U4 mux, D9 tip ESD,
    R19-R26/C23-C29, D1/D2 now SOD-323). Verified: DRC 0 errors /
    0 unconnected, schematic sync clean (75 comps / 61 nets both sides).
    Post-layout fixes:
    - restore exclude_from_pos_files on C19/J1/J2/J5 (wiped again by
    re-layout; CPL correctly excludes C19,J1,J2,J5,R14)
    - point D9 at the project-local 3D model (stock lib ships none)
    - remove stale OK1_LED_A routing left from the mis-wired-label detour
    (1 via + 10 segments, all dangling; net verified intact throughout)
    fab/ regenerated: gerbers/drills/zip, BOM 34 assembled, CPL 70 placed.
    Order-time checks in the JLCPCB preview: U1 QFN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
    [scramble_hat-BOM.csv, scramble_hat-BOM.xlsx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]
2026-07-22 chore: schematic re-save formatting churn from layout session (netlist verified unchanged)
    [sheet_codec.kicad_sch, sheet_input.kicad_sch]
2026-07-22 pcb: minor route/silk tweaks; regen fab + doc PDFs
    Bottom-side route touch-ups and silk adjustments after the guitar-input
    layout. Verified: DRC 0 errors / 0 unconnected, schematic sync clean.
    fab/ regenerated (CPL 70 placed, excludes C19/J1/J2/J5/R14; zip rebuilt
    to match); docs/ schematic + top/bottom silk PDFs refreshed for the
    guitar-input rev.
    [scramble_hat-BOM.xlsx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]
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2026-07-23 case: bracket designs consolidated into brackets/; case model update
    Amp bracket, guitar bracket, and guitar outlet (Plasticity sources +
    STEP exports) now live in brackets/. Generalize the Plasticity
    autosave-history ignore rule to cover any plasticity/ snapshot dir.
    [hat-trik-amp-bracket.stp, hat-trik-guitar-bracket.stp, hat-trik-guitar-outlet.stp]
2026-07-24 pcb: reroute V_PHANTOM away from MIC1N_XLR on B.Cu; regen fab + doc PDFs
    [scramble_hat.kicad_pcb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]
2026-07-25 input: J7 1x4 socket for direct eurorack-module coupling (alt to J1) + R27 0R instrument-mode jumper, both DNP
    [BOM.csv, sheet_input.kicad_sch]
2026-07-26 sw1 optional: DNP by default (phantom-less builds); J7/R27 placed+routed; restore pos-file exclusions; regen fab + docs
    [BOM.csv, scramble_hat-BOM.csv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]
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2026-07-26 pcb: widen HP_L_OUT to MIC1N_XLR spacing on B.Cu; regen fab
    [scramble_hat.kicad_pcb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]
2026-07-26 input: C30 100nF/100V V_PHANTOM bypass at Q1 drain; BOM: datasheet links column, 6 stock-out swaps (OK1 -> EL3H7-VG, 5 resistors -> Yageo), price refresh
    [BOM.csv, sheet_input.kicad_sch]
2026-07-26 pcb: place + route C30 phantom-rail bypass; restore pos-file exclusions; regen fab
    [scramble_hat-BOM.csv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]
2026-07-28 pcb: reroute pass on input section; regen fab
    [scramble_hat-B_Cu.gbr, scramble_hat-B_Mask.gbr, scramble_hat-B_Paste.gbr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]
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2026-07-28 pcb: layout tweak on input corridor; regen fab + doc PDFs
    [scramble_hat.kicad_pcb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]
2026-08-01 pcb: input-corridor tweaks; J6 display header now DNP; regen fab + docs
    - J6 hand-fit per build; eurorack builds don't need it at all (the
    Synthia interposer drives the display directly from its own socket)
    - BOM: J6 marked DNP; fab assembly split updated (JLC THT = J3/J4 only;
    CPL 69 placed, 9 exclusions: C19 J1 J2 J5 J6 J7 R14 R27 SW1)
    - restore exclude_from_pos flags wiped by layout sessions
    - README: power/host notes (USB-C + PoE concurrency, hot-plug pop,
    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
    [BOM.csv, scramble_hat-BOM.csv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]
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2026-08-01 brackets: update amp + guitar brackets; add amp faceplate and eurorack bracket
    - amp and guitar mounting brackets reworked (plasticity + exported STPs)
    - new: amp faceplate STP, eurorack bracket (work in progress, no STP yet)
    [hat-trik-amp-bracket.stp, hat-trik-amp-faceplate.stp, hat-trik-guitar-bracket.stp]
2026-08-17 sch+pcb: dual-host mezzanine pinout (ESP32-P4 + Pico) — I2C to J3.1/2, BCLK/LRCK adjacent, MCLK/DET on J4.6/7, new R28 MCLK series link; regen fab + docs; add pinout graphic
    [BOM.csv, scramble_hat-BOM.csv, scramble_hat-BOM.xlsx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]
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2026-08-18 pcb: silkscreen tidy-up; remove vestigial V_FILT stub near J1 R pad (cleared clearance error); regen fab + silk PDFs
    [scramble_hat-BOM.xlsx, scramble_hat.kicad_pcb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]
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2026-08-23 repo: move mechanical CAD (case/, brackets/) out of the repo
    Plasticity models, brackets, and case STEP exports now live in a separate
    mechanical-CAD directory. Update README structure notes and .gitignore
    accordingly.
    [eth-side.stp, hat-trik-amp-bracket.stp, hat-trik-amp-faceplate.stp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]
